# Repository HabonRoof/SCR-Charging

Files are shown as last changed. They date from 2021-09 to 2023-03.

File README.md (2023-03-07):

# Sinusoidal Charger with Optimized Frequency Tracking for Li-ion Batteries

The purpose of this thesis is to develop a sinusoidal charger that can track the optimized frequency of Li-ion batteries.
In this study, the optimized AC impedance frequency tracking is firstly carried out for various types of lithium-ion batteries with different aging degrees to achieve the goal of shortening the charging time and increasing the charging efficiency. 
The digital control core of the charger developed in this thesis uses the F280049C digital signal controller (DSC) produced by Texas Instruments and adopts the Powell algorithm to quickly search for the best sinusoidal charging current frequency when the battery state-of-charge (SOC) is 0%, 15% and 30%, which ensures the lowest impedance during charging.
The proposed prototyping circuit uses field effect transistors as voltage-to-current converters and utilizes digital finite impulse response filters and proportional-integral controllers to stabilize the charging current. 
The charger can provide a maximum charging power of 21W. The experimental results show that the proposed sinusoidal charger can shorten the charging time by 3.66%, reduce the charging loss by 1.08% and reduce the temperature rise by 27.16% compared with the traditional constant current and constant voltage charging method.
Keyword: Sinusoidal Charging, Li-ion Batteries, Fast Charging technique, On-line Optimized Impedance Tracking

[Thesis link](https://ndltd.ncl.edu.tw/cgi-bin/gs32/gsweb.cgi/login?o=dwebmge)

# Outlook
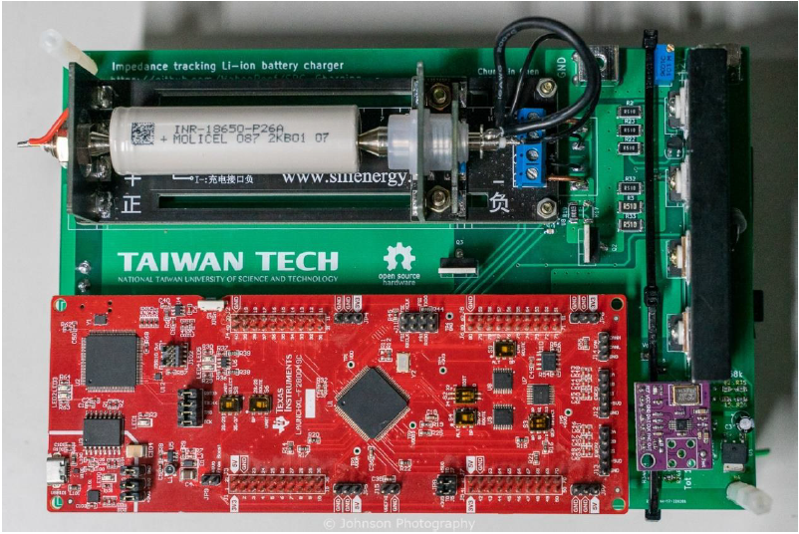
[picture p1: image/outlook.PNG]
Front side


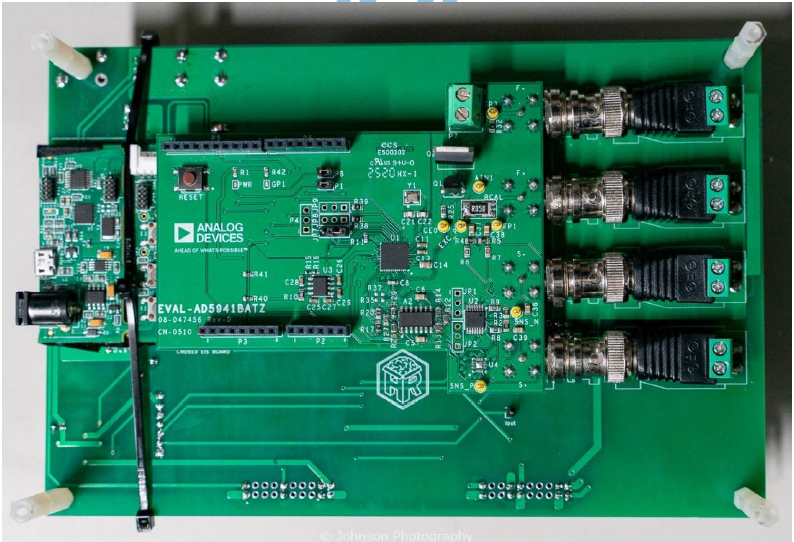
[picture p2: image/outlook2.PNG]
Back side


# File disceiption
#### AD5940_BATImpedance
- ADICuP3029 project, to control and calculate real/imaginary part of impedance. Include FFT calculation.
- Source code for AD5940 battery EIS measurment module (CN0510), modified and origin by Analog Device .Inc.
#### KiCad
- Schematic file and PCB file for main board, which offer CN0510, F280049C Launch Pad and AD9833 waveform generator module a base.
#### RippleCharging
- The main CCS project folder, control the behavior of sinusoidal charger, waveform generator, MOSFET relay, EIS measurement module.
#### ad5940lib
- Companion library of AD5940_BATImpedance folder

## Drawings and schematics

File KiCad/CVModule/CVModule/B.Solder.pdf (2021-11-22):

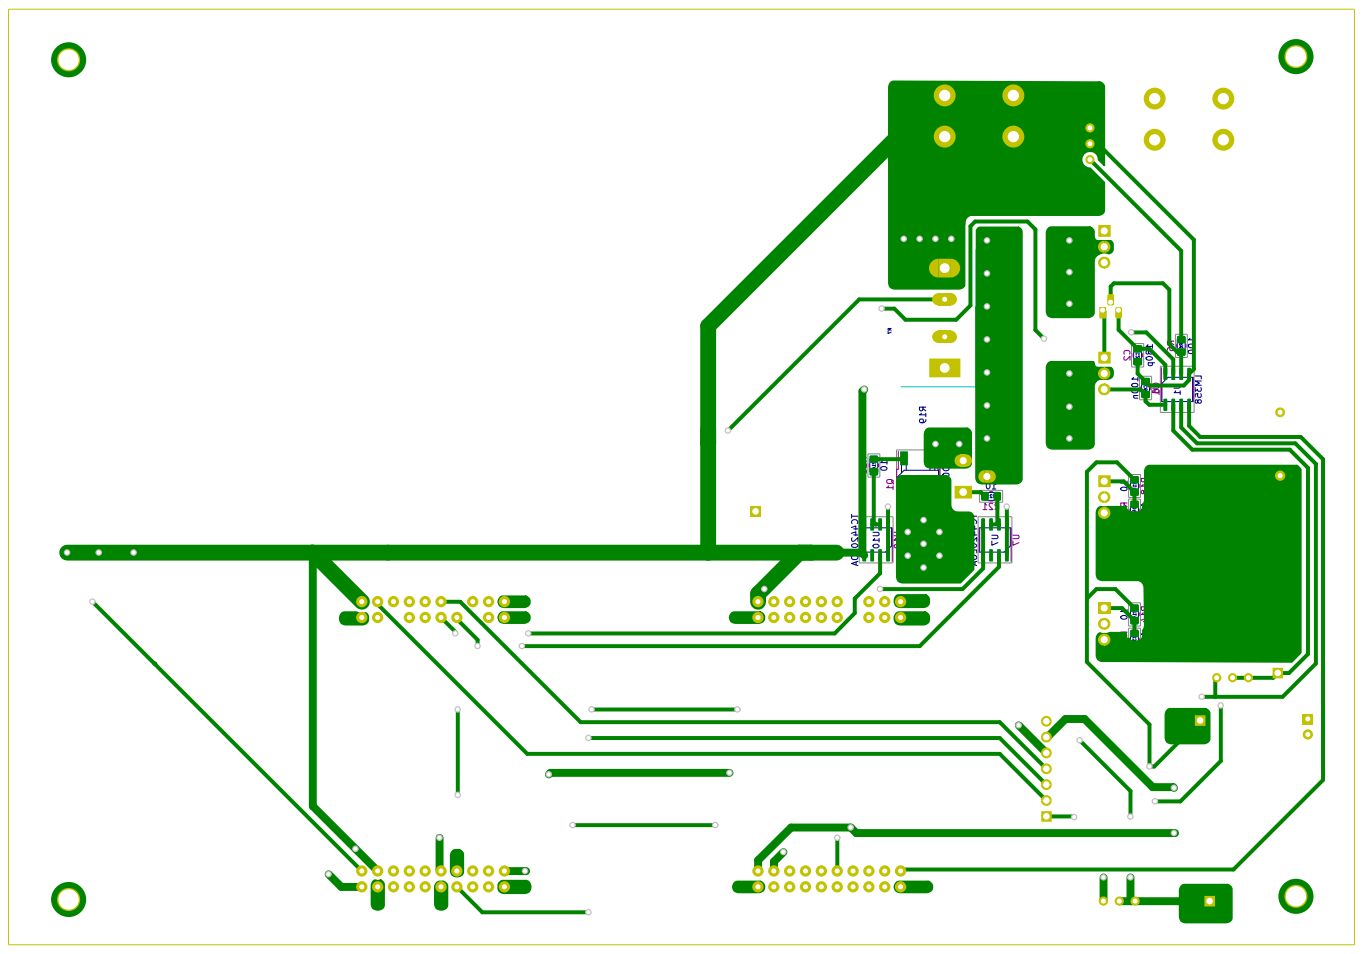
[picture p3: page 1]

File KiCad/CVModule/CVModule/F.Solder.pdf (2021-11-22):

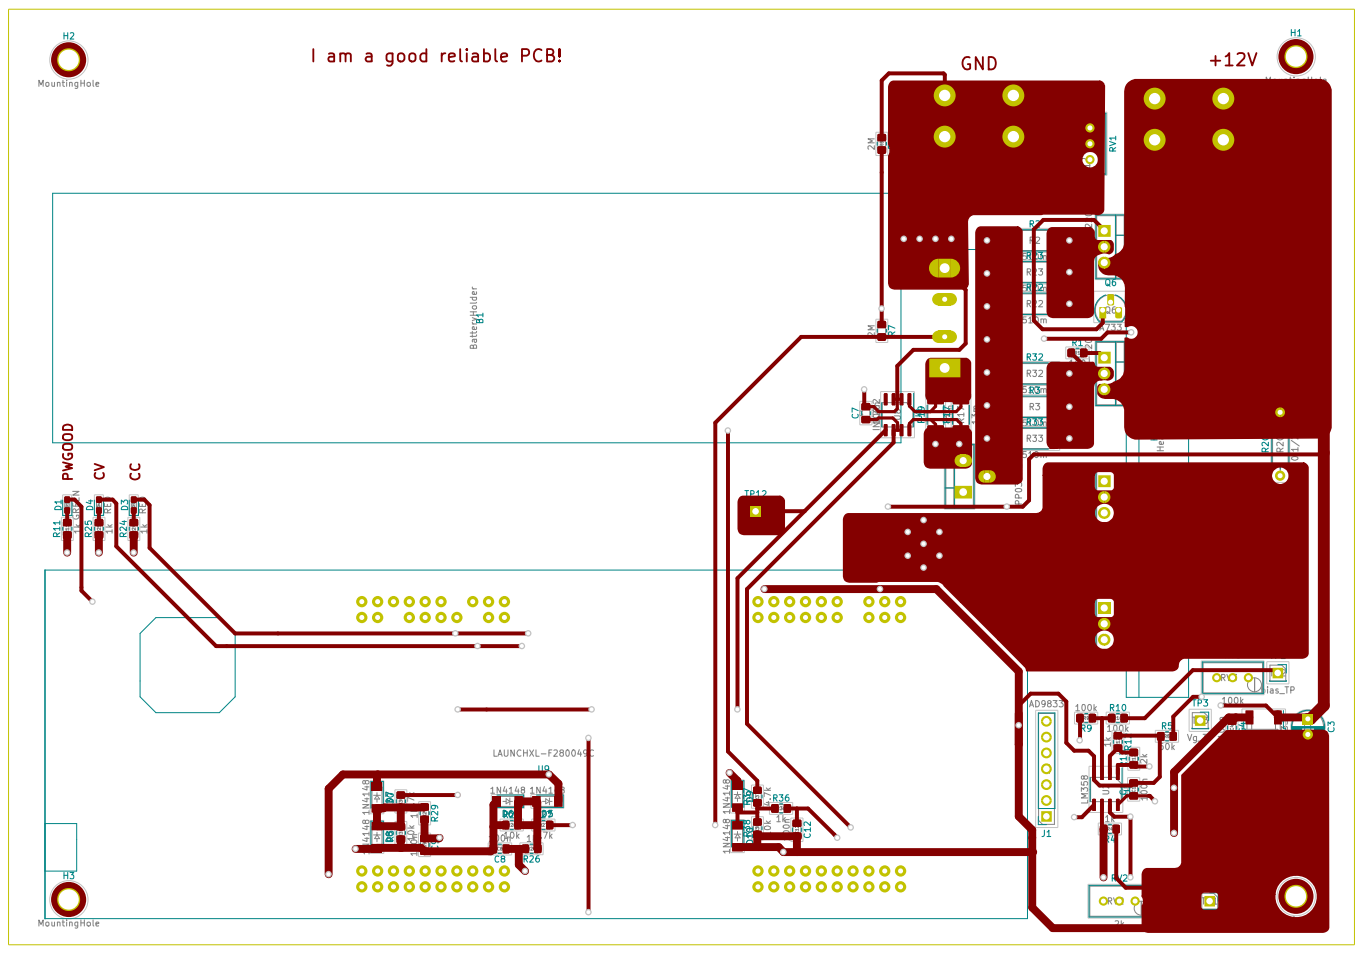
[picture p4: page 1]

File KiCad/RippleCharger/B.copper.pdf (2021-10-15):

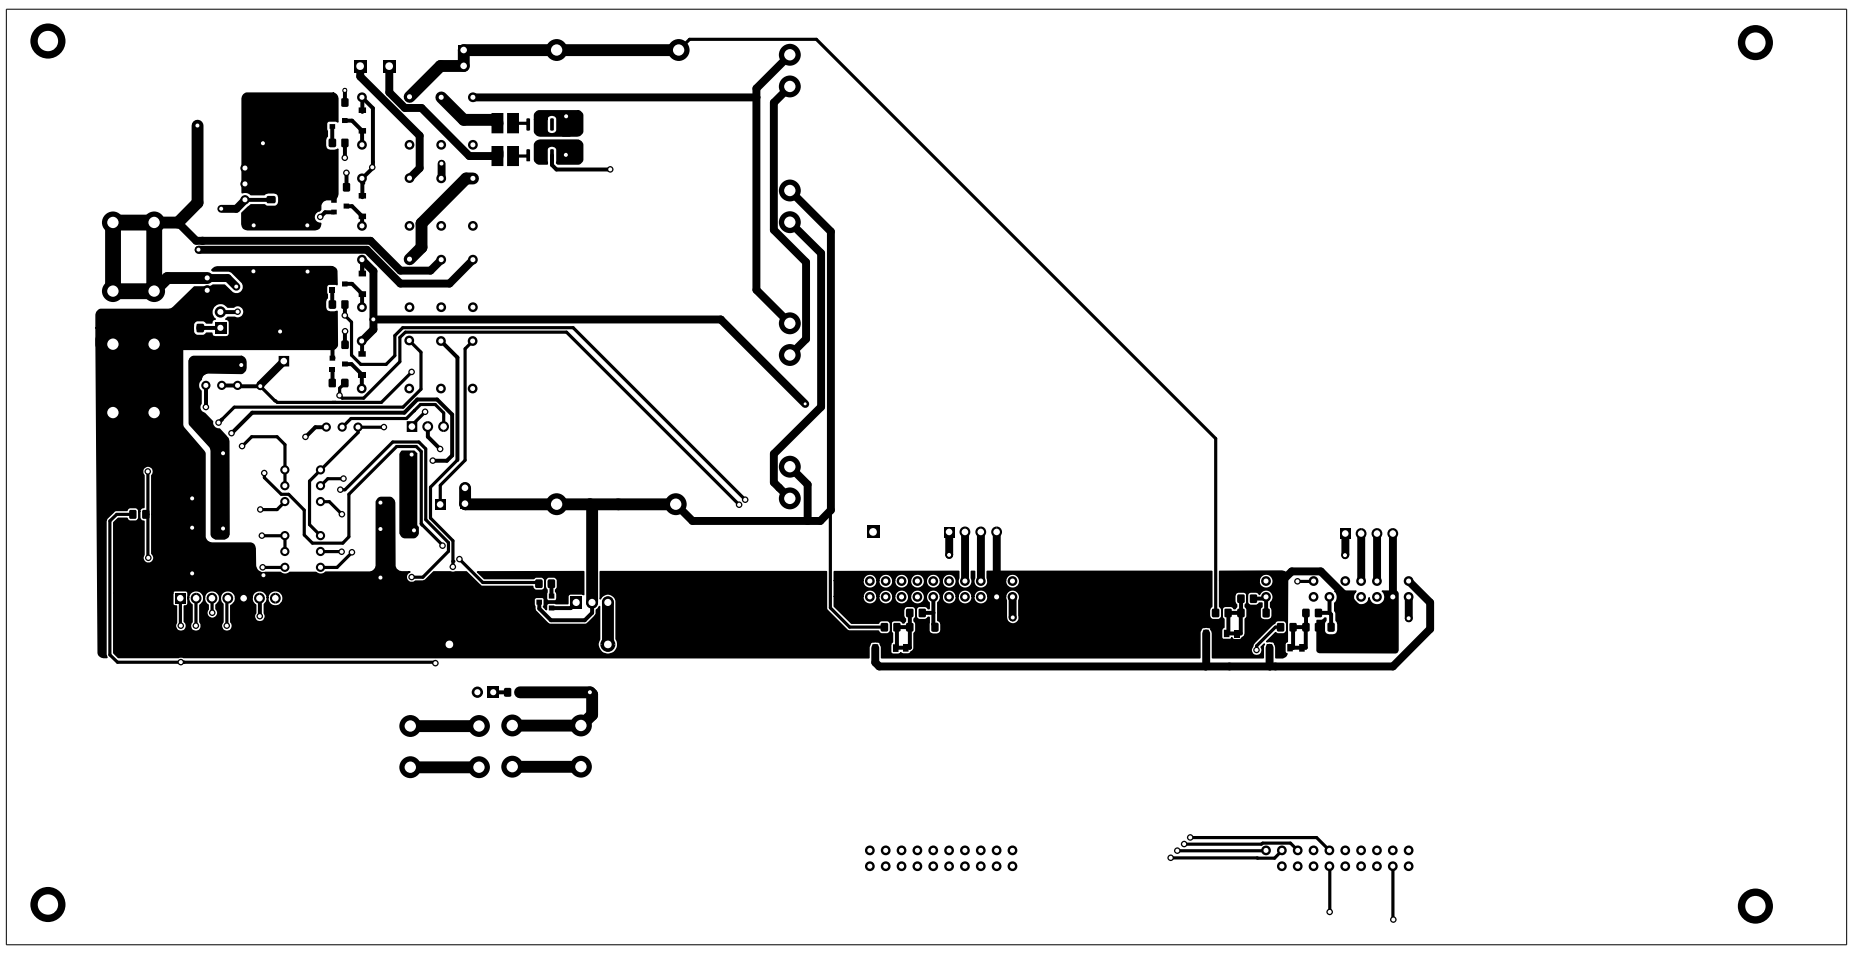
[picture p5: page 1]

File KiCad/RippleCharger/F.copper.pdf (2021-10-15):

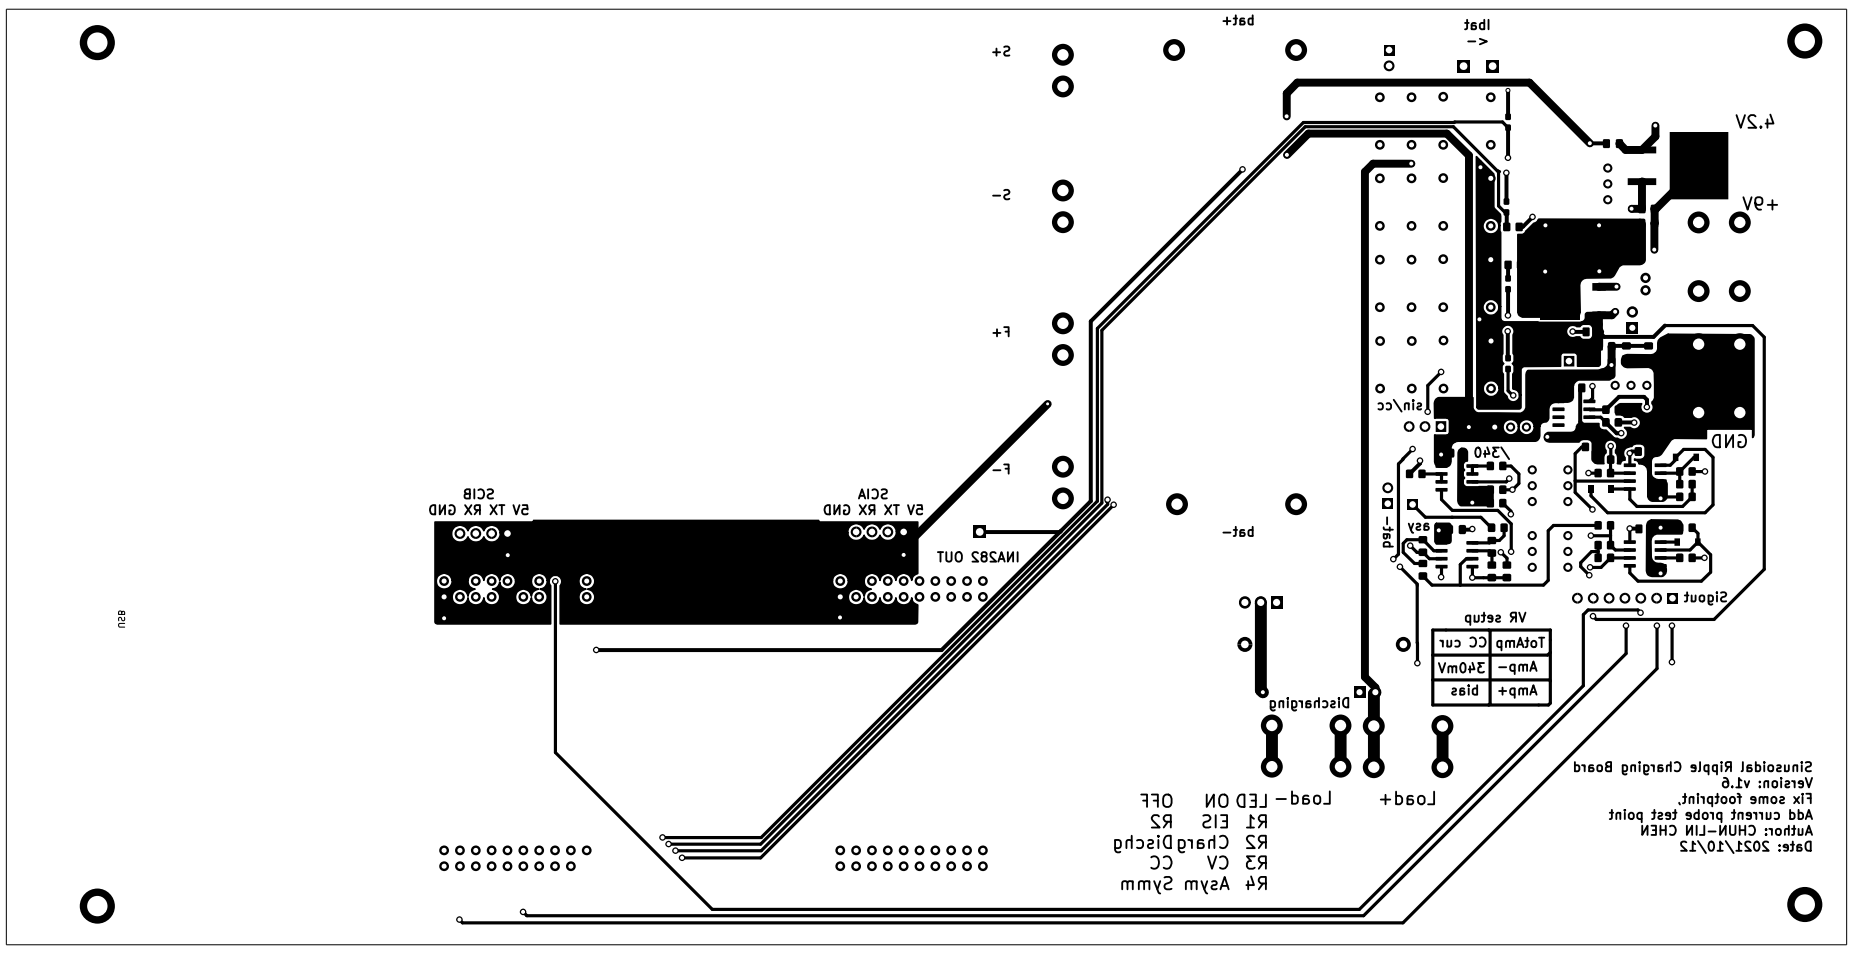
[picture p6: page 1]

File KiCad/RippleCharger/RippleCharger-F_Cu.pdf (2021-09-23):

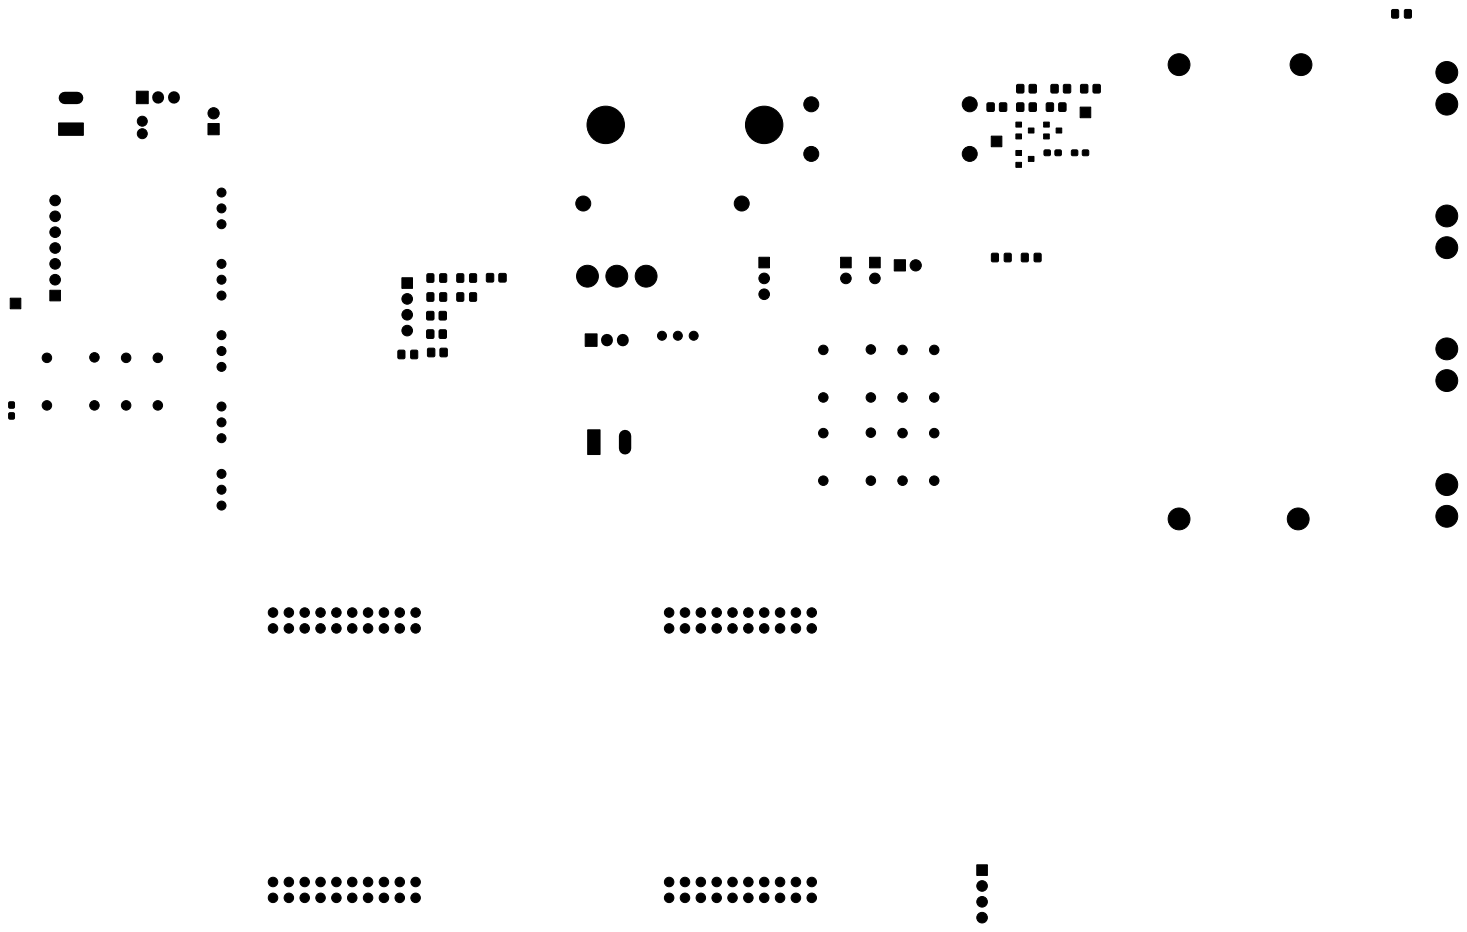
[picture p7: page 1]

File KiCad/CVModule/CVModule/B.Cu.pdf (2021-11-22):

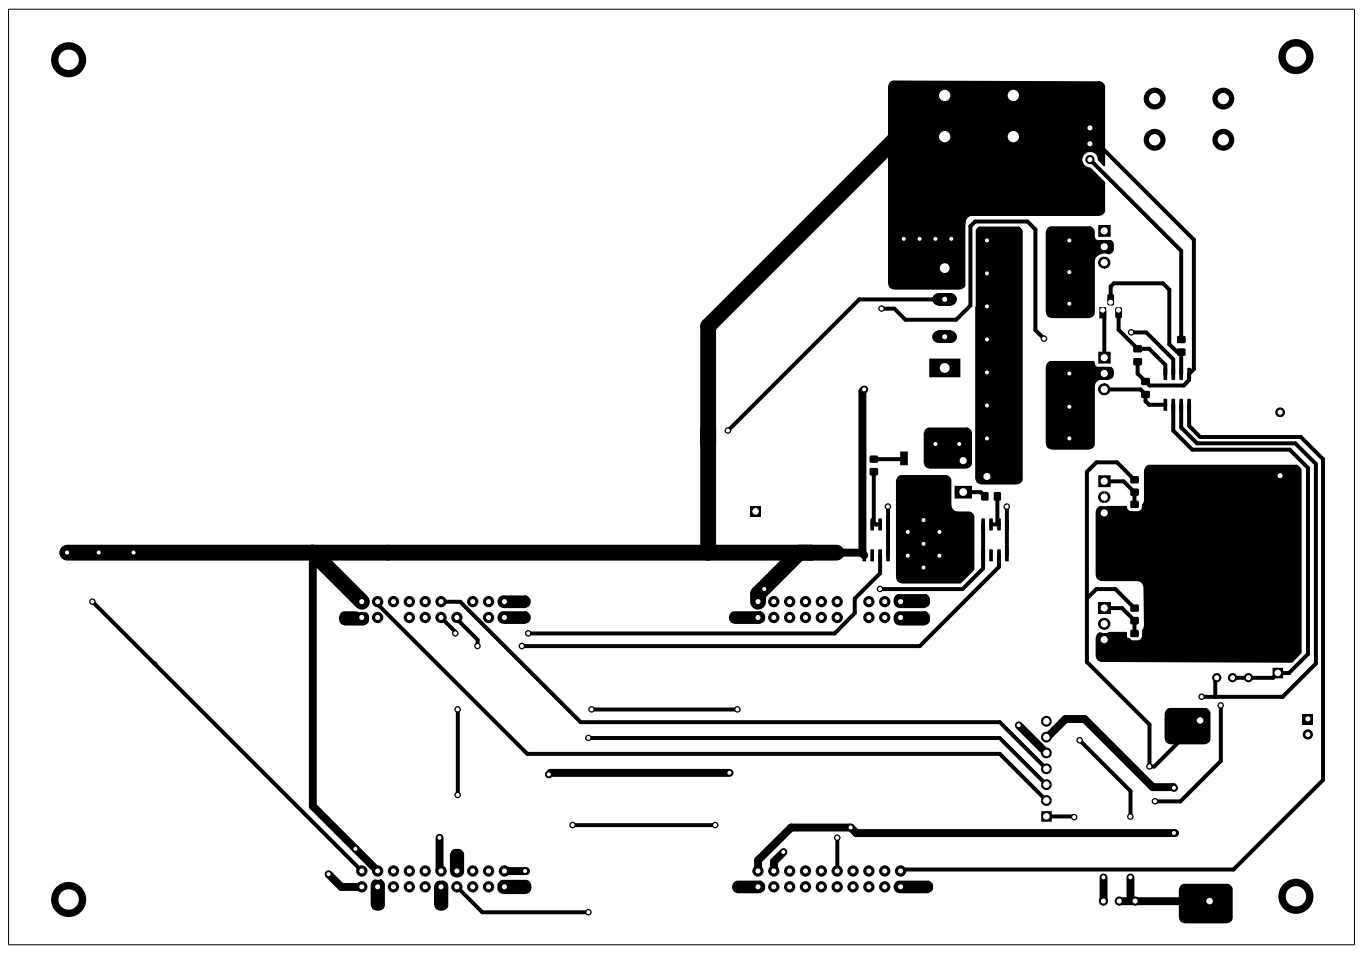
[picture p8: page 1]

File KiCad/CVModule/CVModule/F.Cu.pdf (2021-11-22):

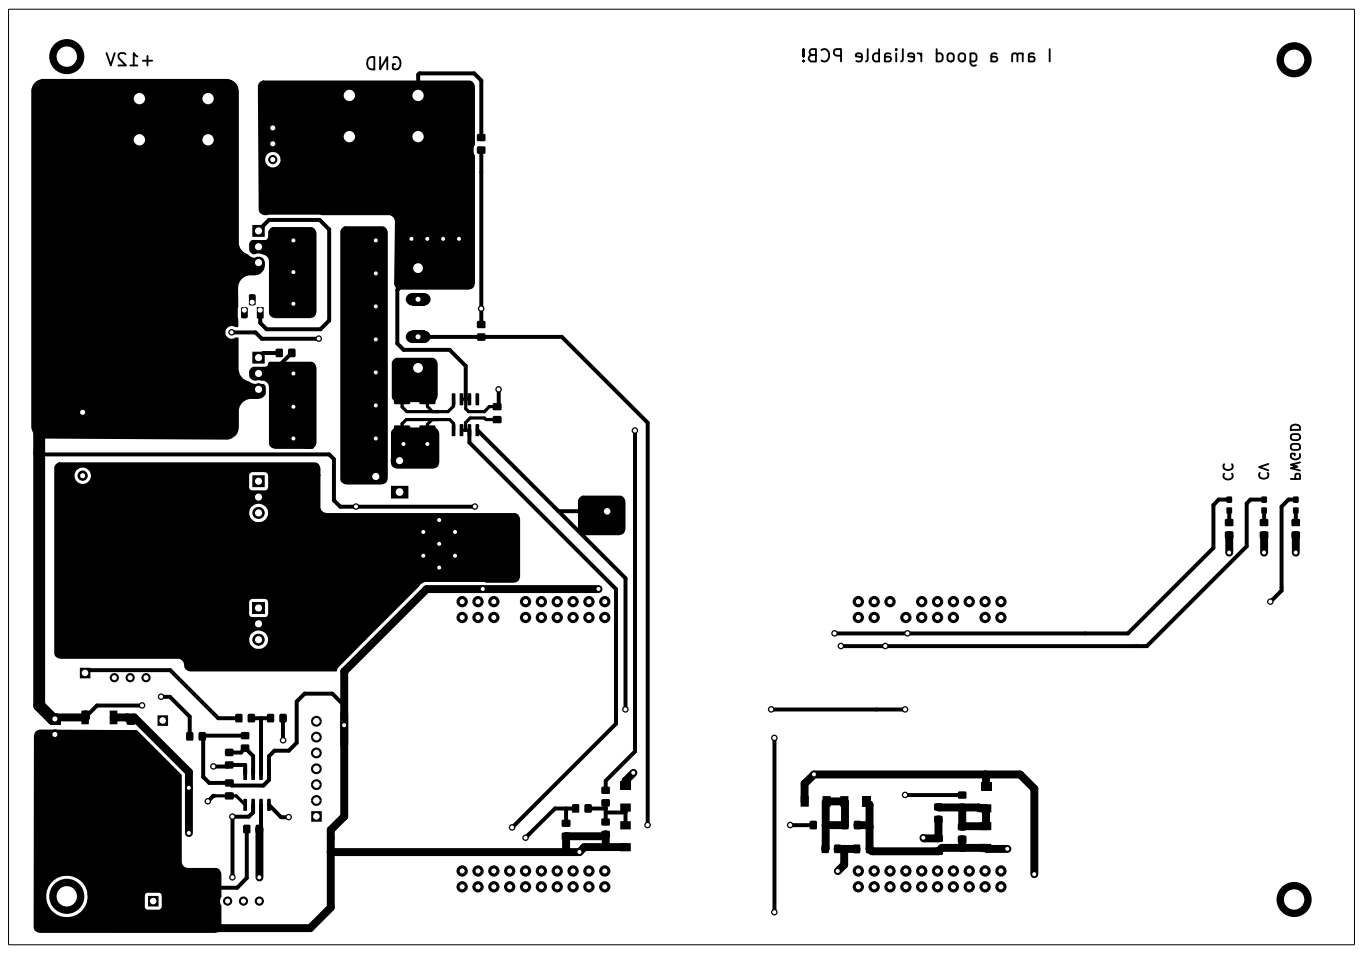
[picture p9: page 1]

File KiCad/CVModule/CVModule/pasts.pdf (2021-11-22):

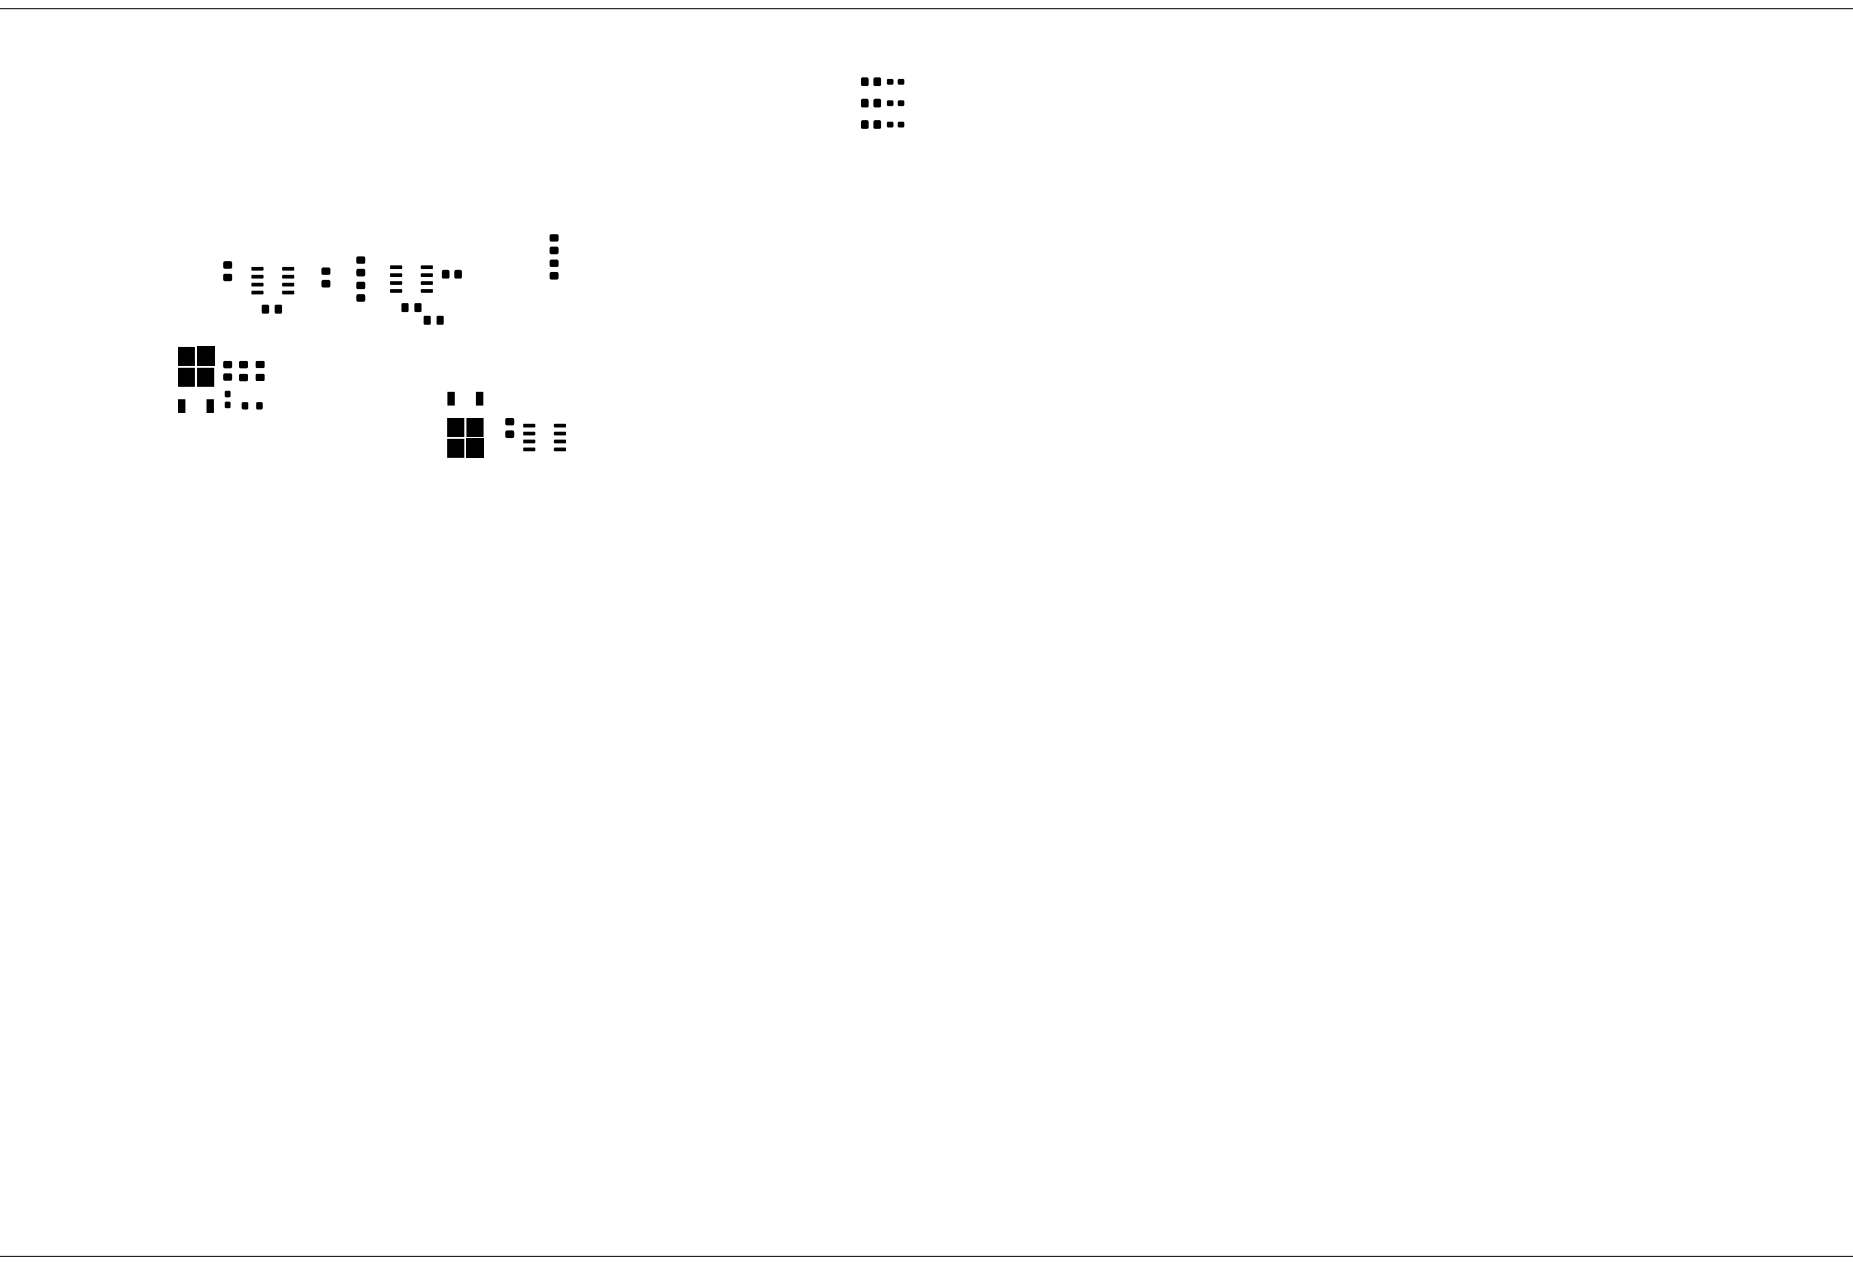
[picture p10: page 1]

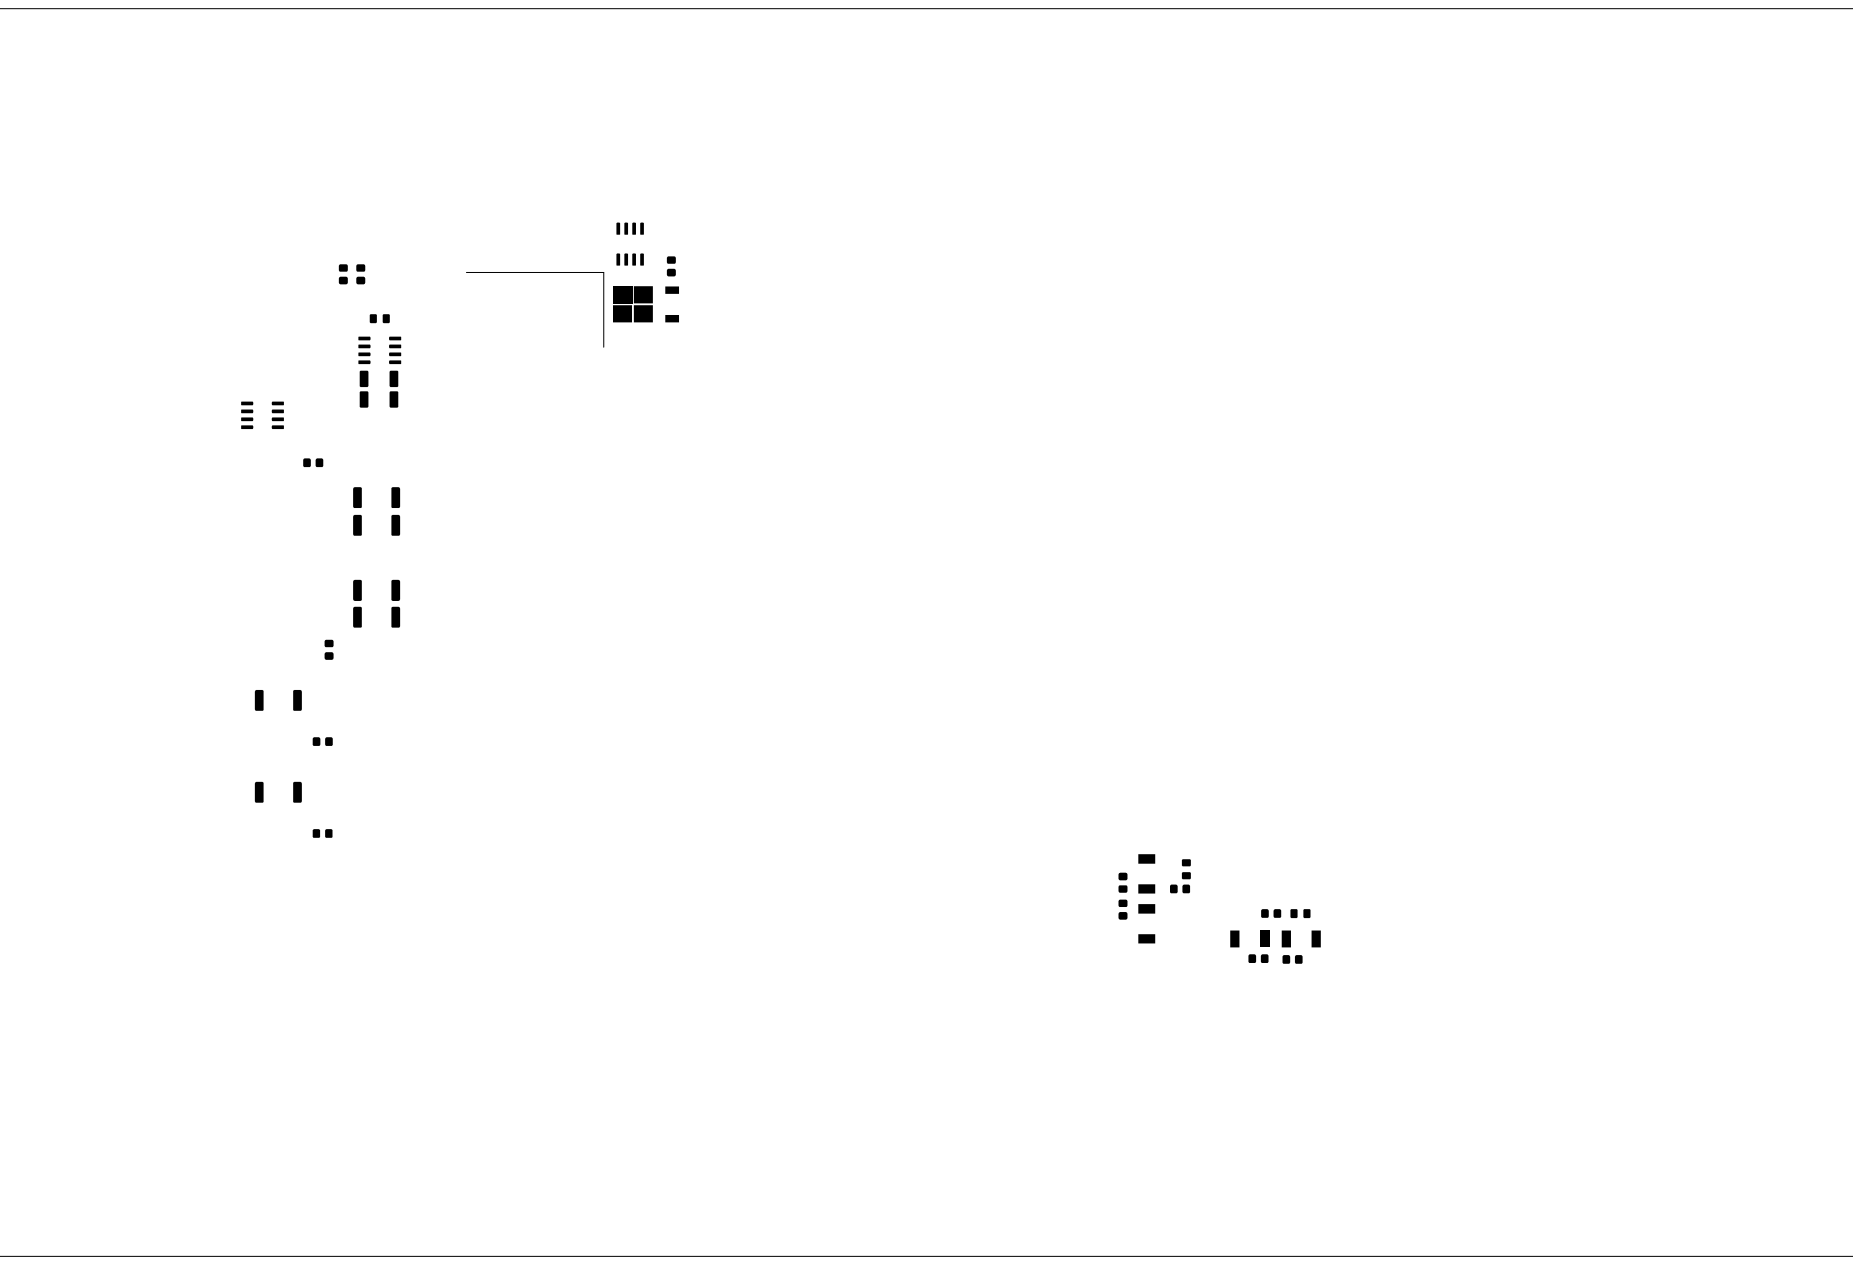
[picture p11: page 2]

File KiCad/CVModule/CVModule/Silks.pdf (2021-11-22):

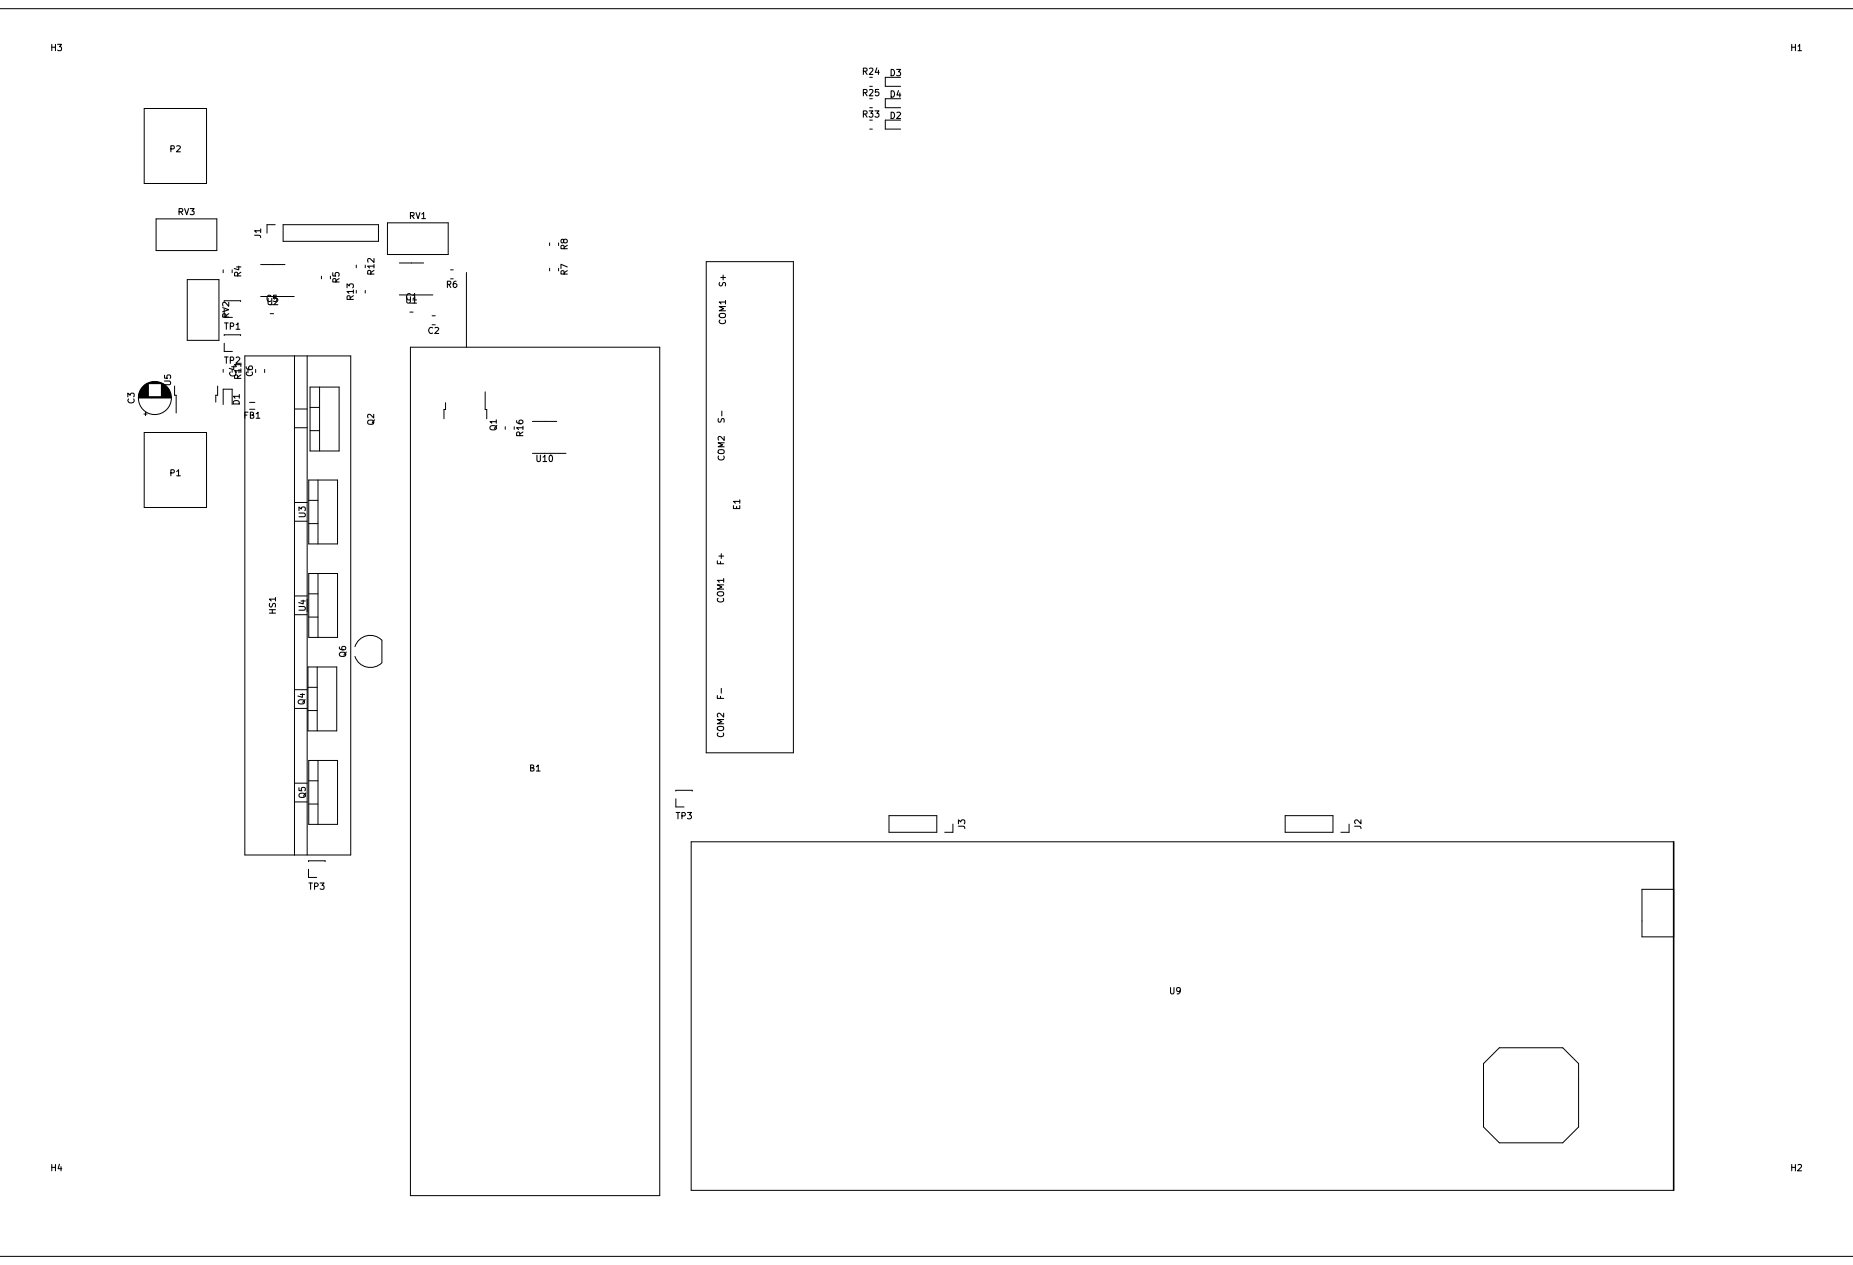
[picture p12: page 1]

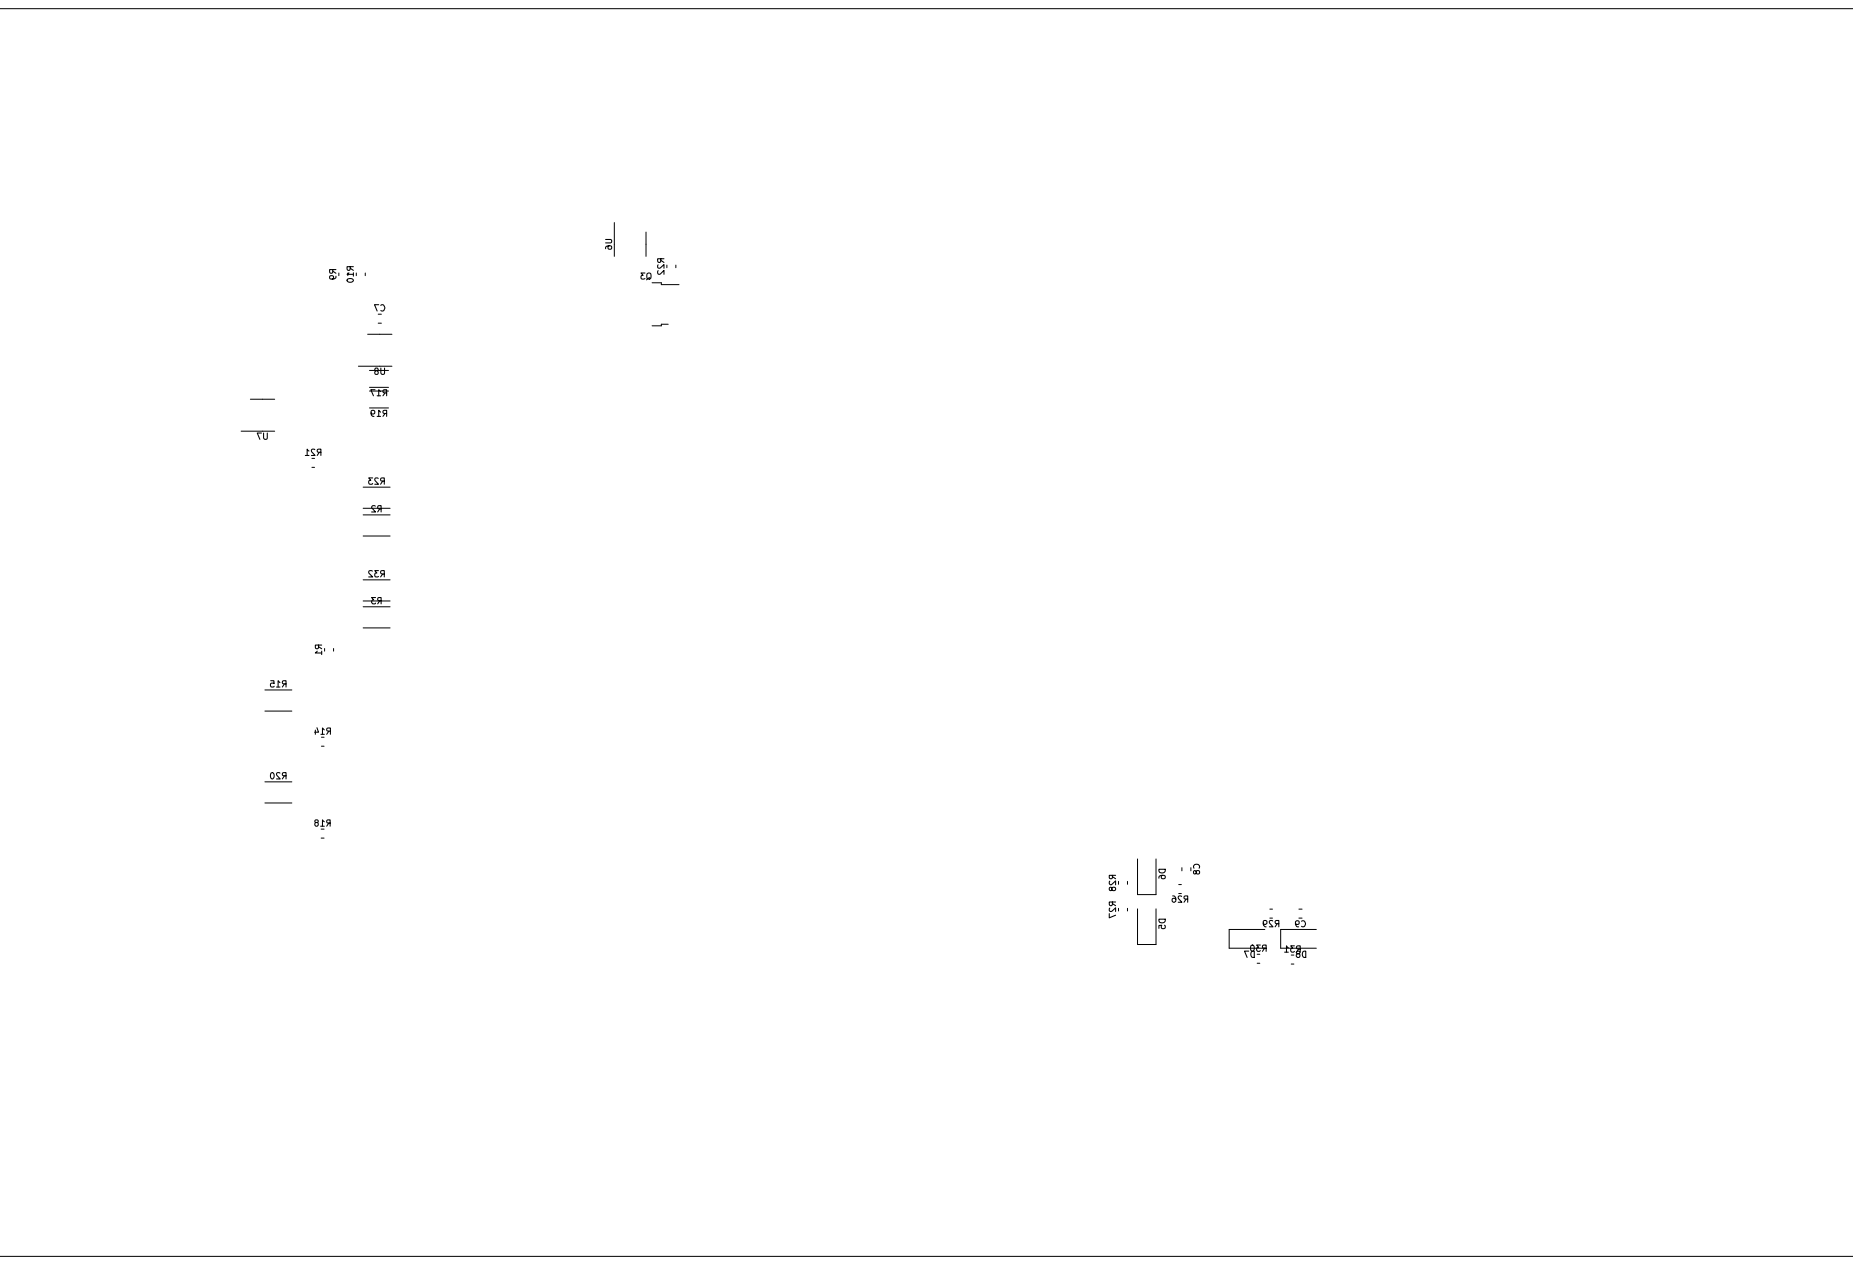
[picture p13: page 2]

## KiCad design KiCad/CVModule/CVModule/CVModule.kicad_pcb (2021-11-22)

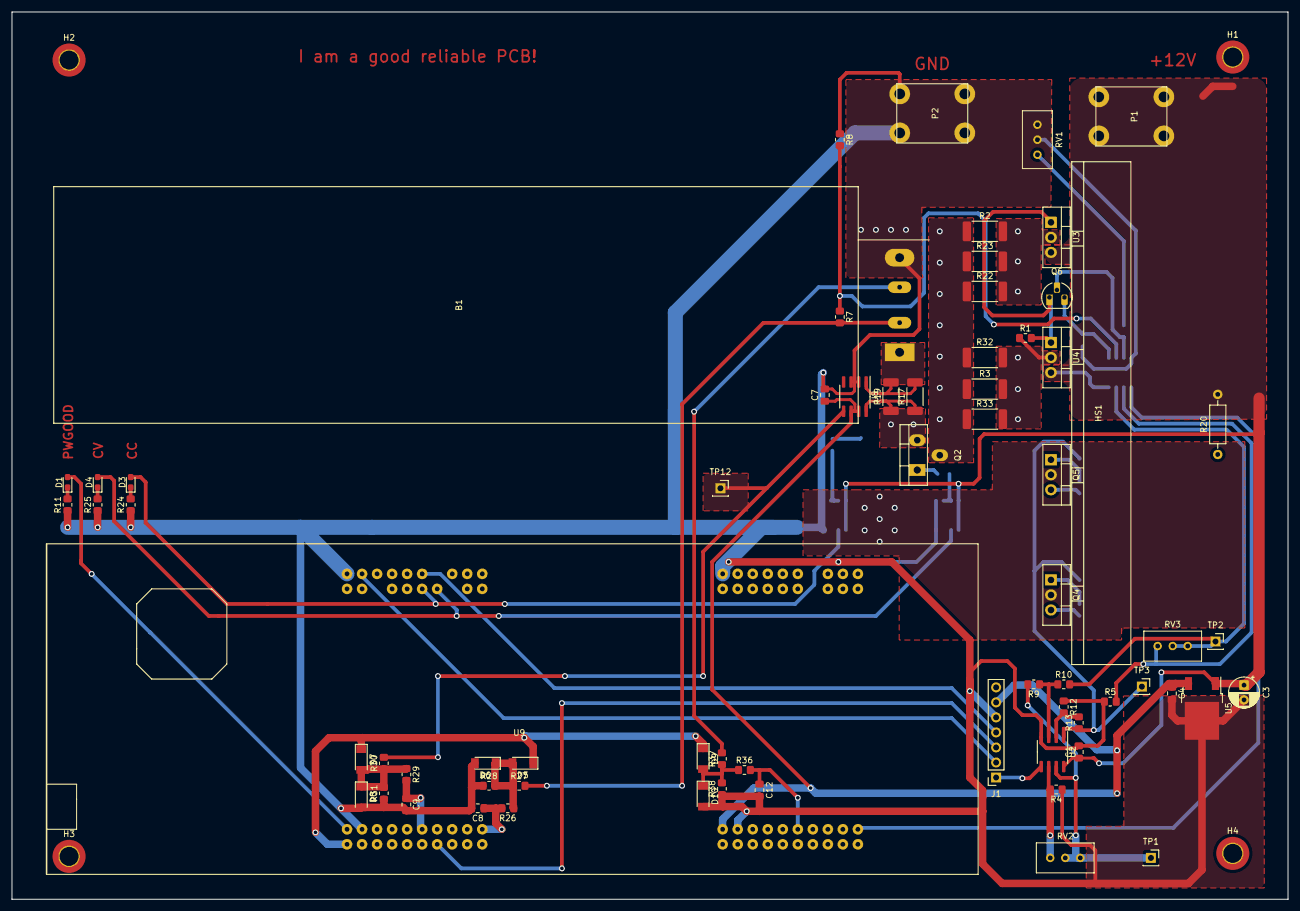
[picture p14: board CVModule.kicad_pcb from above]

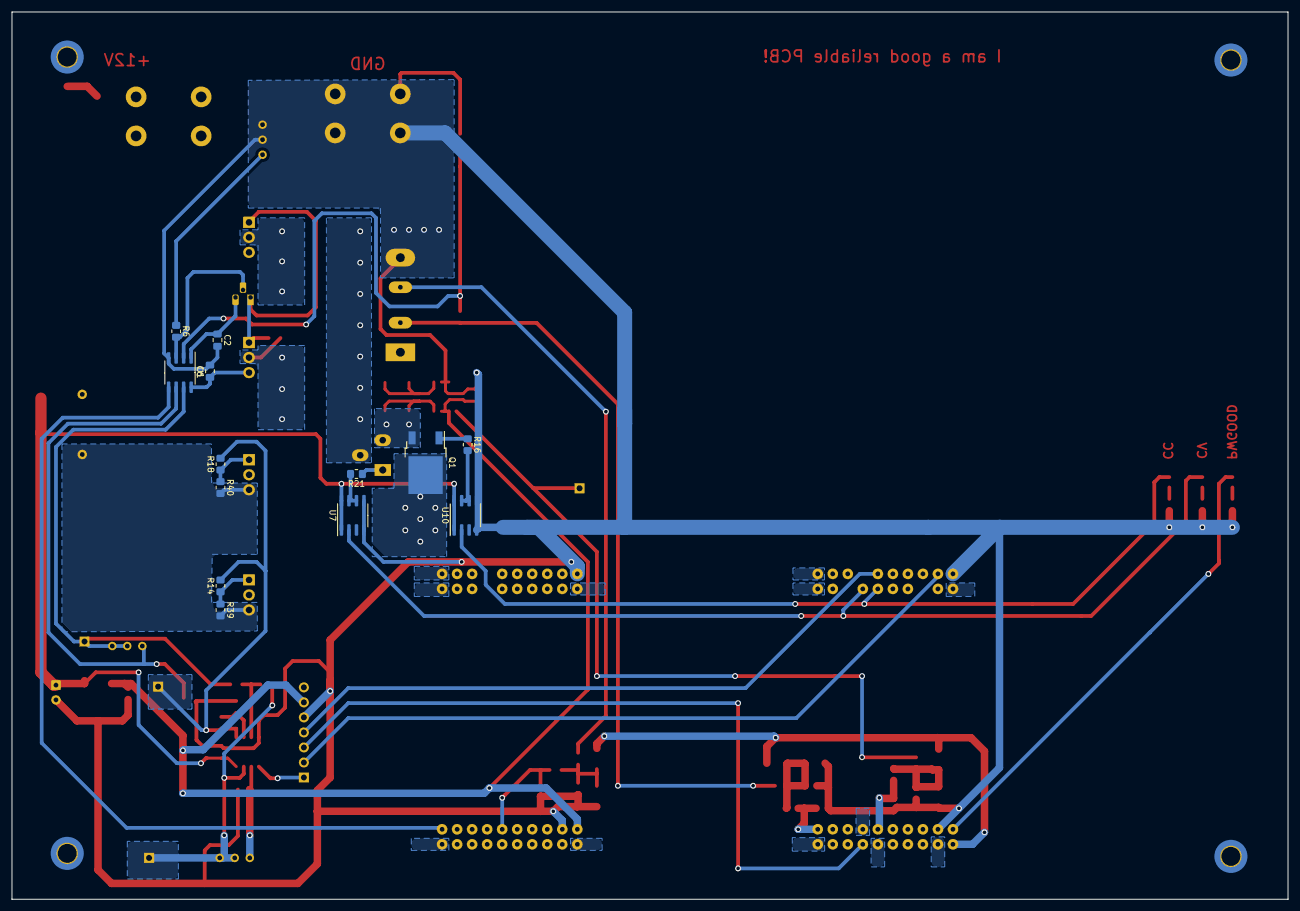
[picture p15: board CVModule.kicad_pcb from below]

Board: 2 copper layers, 215.7 x 150.0 mm, 85 parts (13 on the bottom side), 48 nets.

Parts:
B1: BatteryHolder; BatteryHolder-Single
C1, C4, C6, C7, C8, C9, C12: 100n; C_0805_2012Metric_Pad1.18x1.45mm_HandSolder
C2: 180p; C_0805_2012Metric_Pad1.18x1.45mm_HandSolder
C3: 0.33u; CP_Radial_D5.0mm_P2.50mm
D1: GREEN; LED_0603_1608Metric_Pad1.05x0.95mm_HandSolder
D3, D4: RED; LED_0603_1608Metric_Pad1.05x0.95mm_HandSolder
D5, D6, D7, D8, D9, D10: 1N4148; D_MiniMELF
H1, H2, H3, H4: MountingHole; MountingHole_3.2mm_M3_DIN965_Pad_TopBottom
HS1: Heatsink; Heatsink_80mmx3mm_4hole_black
J1: AD9833; PinSocket_1x07_P2.54mm_Vertical
P1: +12Vin; IOPad
P2: GND; IOPad
Q1: 600N25NG; TO-252-2
Q2: IPP030N10N3; TO220-3_Vertical_T
Q4, Q5: IRFR9024; TO-220-3_Vertical
Q6: A733; TO-92_HandSolder
R1, R6: 100; R_0805_2012Metric_Pad1.20x1.40mm_HandSolder
R2, R3, R22, R23, R32, R33: 510m; R_2512_6332Metric_Pad1.40x3.35mm_HandSolder
R4, R11, R12, R24, R25, R26, R29, R36: 1k; R_0805_2012Metric_Pad1.20x1.40mm_HandSolder
R5: 50k; R_0805_2012Metric_Pad1.20x1.40mm_HandSolder
R7, R8: 2M; R_0805_2012Metric_Pad1.20x1.40mm_HandSolder
R9, R10: 100k; R_0805_2012Metric_Pad1.20x1.40mm_HandSolder
R13: 2k; R_0805_2012Metric_Pad1.20x1.40mm_HandSolder
R14, R16, R18, R21: 10; R_0805_2012Metric_Pad1.20x1.40mm_HandSolder
R17, R19: 13m; R_2010_5025Metric_Pad1.40x2.65mm_HandSolder
R20: 0.1/2W; R_Axial_DIN0207_L6.3mm_D2.5mm_P10.16mm_Horizontal
R27, R30, R37: 4.7k; R_0805_2012Metric_Pad1.20x1.40mm_HandSolder
R28, R31, R38, R39, R40: 10k; R_0805_2012Metric_Pad1.20x1.40mm_HandSolder
RV1: 1k; Potentiometer_Bourns_3296W_Vertical
RV2: 2k; Potentiometer_Bourns_3296W_Vertical
RV3: 100k; Potentiometer_Bourns_3296W_Vertical
TP1: sig_TP; PinSocket_1x01_P2.54mm_Vertical
TP2: bias_TP; PinSocket_1x01_P2.54mm_Vertical
TP3: Vg_TP; PinSocket_1x01_P2.54mm_Vertical
TP12: Iout; PinSocket_1x01_P2.54mm_Vertical
U1, U2: LM358; SOIC-8_3.9x4.9mm_P1.27mm
U3, U4: LM317_TO-220; TO-220-3_Vertical
U5: L7805; TO-252-2
U7, U10: TC4420EOA; SOIC-8_3.9x4.9mm_P1.27mm
U8: INA282; SOIC-8_3.9x4.9mm_P1.27mm
U9: LAUNCHXL-F280049C; LANCHXL-F280049C

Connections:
+3V3: D5.1, D7.1, D9.1, U9.1
+4.2V: Q2.2, R2.1, R3.1, R22.1, R23.1, R32.1, R33.1
+5V: C4.1, C7.1, D1.2, J1.6, U5.3, U8.6, U8.7, U9.21, U9.61
+12V: C1.1, C3.1, C6.1, P1.1, R20.2, U1.8, U2.8, U3.3, U4.3, U5.1, U7.1, U7.8, U10.1, U10.8
-BATT: B1.4, C1.2, C2.2, C3.2, C4.2, C6.2, C7.2, C8.2, C9.2, C12.2, D6.2, D8.2, D10.2, J1.5, P2.1, R4.1, R5.1, R8.1, R11.1, R12.1, R24.1, R25.1, R28.1, R31.1, R38.1, RV1.2, RV1.3, U1.4, U2.4, U5.2, U7.4, U7.5, U8.2, U8.3, U9.20, U9.22, U9.60, U9.62, U10.4, U10.5
CC_g: D3.2, U9.35, U10.2
CS: J1.2, U9.19
CV_g: D4.2, U7.2, U9.34
Iout: R30.2, TP12.1, U8.5
MOSI: J1.4, U9.15
unnamed: C2.1, Q6.3, U1.1
unnamed: D1.1, R11.2
unnamed: D3.1, R24.2
unnamed: D4.1, R25.2
unnamed: D5.2, D6.1, R26.1, R27.1, R28.2
unnamed: D7.2, D8.1, R29.1, R30.1, R31.2
unnamed: D9.2, D10.1, R36.1, R37.1, R38.2
unnamed: Q1.1, R16.1
unnamed: Q1.2, Q4.2, Q5.2
unnamed: Q2.1, R21.1
unnamed: Q4.1, R14.1, R39.1
unnamed: Q4.3, Q5.3, R20.1, R39.2, R40.2
unnamed: Q5.1, R18.1, R40.1
unnamed: Q6.1, R1.2, U3.1, U4.1
unnamed: Q6.2, R6.2, U1.3
unnamed: R1.1, R3.2, R32.2, R33.2, U4.2
unnamed: R2.2, R22.2, R23.2, U3.2
unnamed: R4.2, RV2.3, U2.6
unnamed: R5.2, RV3.3, U1.6
unnamed: R6.1, RV1.1
unnamed: R7.1, R8.2, U1.2
unnamed: R9.2, RV2.1, RV2.2, TP1.1, U2.7
unnamed: R9.1, R10.1, U2.3
unnamed: R10.2, RV3.1, RV3.2, TP2.1, U1.7
unnamed: R12.2, R13.2, U2.2
Q1_g: R16.2, U10.6, U10.7
Q2_g: R21.2, U7.6, U7.7
Rs+: Q1.3, Q2.3, R17.1, R19.1, U8.8
Rs-: B1.1, R17.2, R19.2, U8.1
SCLK: J1.3, U9.7
Vbat+: C8.1, R26.2, U9.30
Vbat-: C12.1, R36.2, U9.66
Viout: C9.1, R29.2, U9.26
bat+: B1.2, R7.2, R27.2
bat-: B1.3, R37.2
bias_ctl: U1.5, U9.70
signal: R13.1, R14.2, R18.2, TP3.1, U2.1
sigout: J1.1, U2.5

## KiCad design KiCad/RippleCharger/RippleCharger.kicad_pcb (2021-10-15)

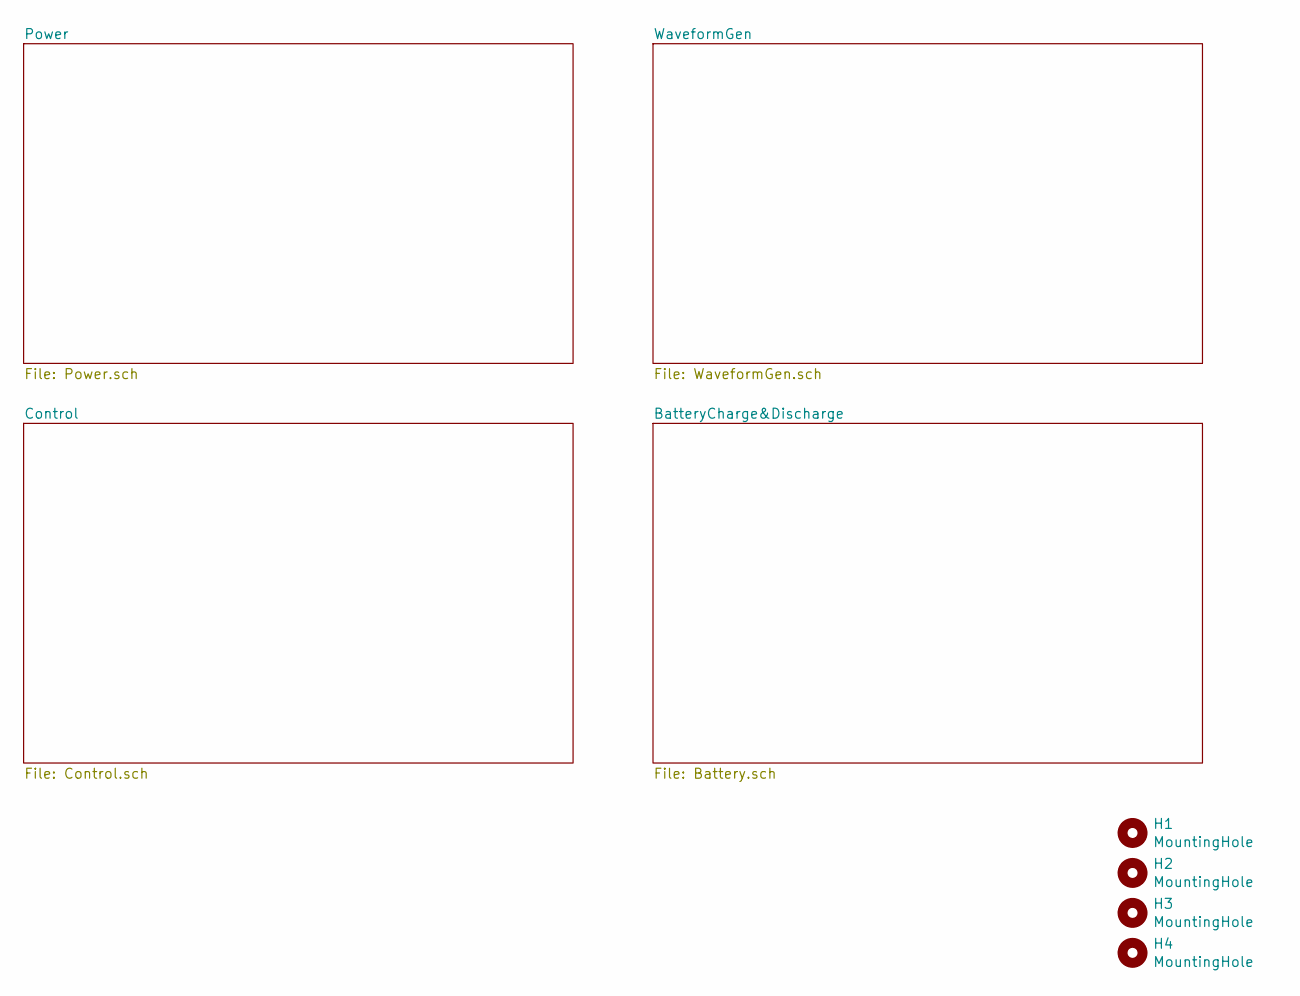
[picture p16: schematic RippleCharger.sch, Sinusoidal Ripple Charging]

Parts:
H1, H2, H3, H4: MountingHole; MountingHole_3.2mm_M3_DIN965_Pad_TopBottom

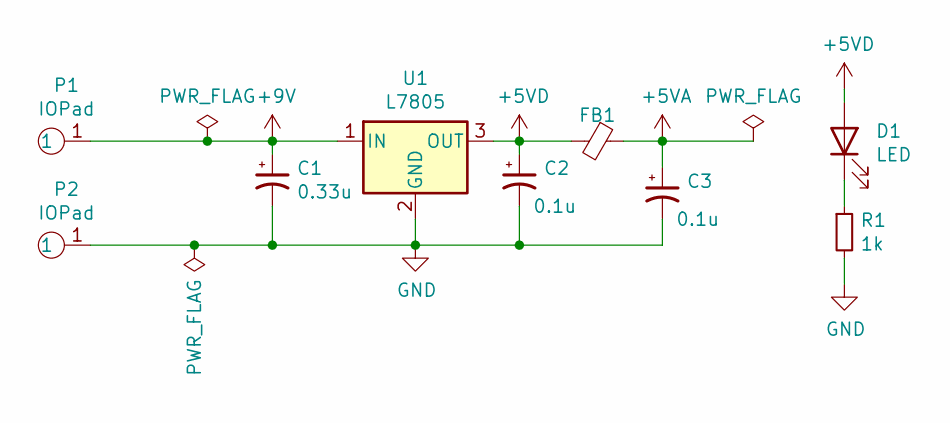
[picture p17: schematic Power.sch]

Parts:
C1: 0.33u; C_Radial_D5.0mm_H11.0mm_P2.00mm
C2, C3: 0.1u; C_0805_2012Metric_Pad1.18x1.45mm_HandSolder
D1: LED; LED_D3.0mm
FB1: Ferrite_Bead_Small; R_0805_2012Metric_Pad1.20x1.40mm_HandSolder
P1, P2: IOPad
R1: 1k; R_0805_2012Metric_Pad1.20x1.40mm_HandSolder
U1: L7805; TO-252-2

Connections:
+5VA: C3.1, FB1.1; also elsewhere on the board
+5VD: C2.1, D1.2 (A), FB1.2, U1.3 (OUT); also elsewhere on the board
+9V: C1.1, P1.1, U1.1 (IN); also elsewhere on the board
GND: C1.2, C2.2, C3.2, P2.1, R1.2, U1.2 (GND); also elsewhere on the board
unnamed: D1.1 (K), R1.1

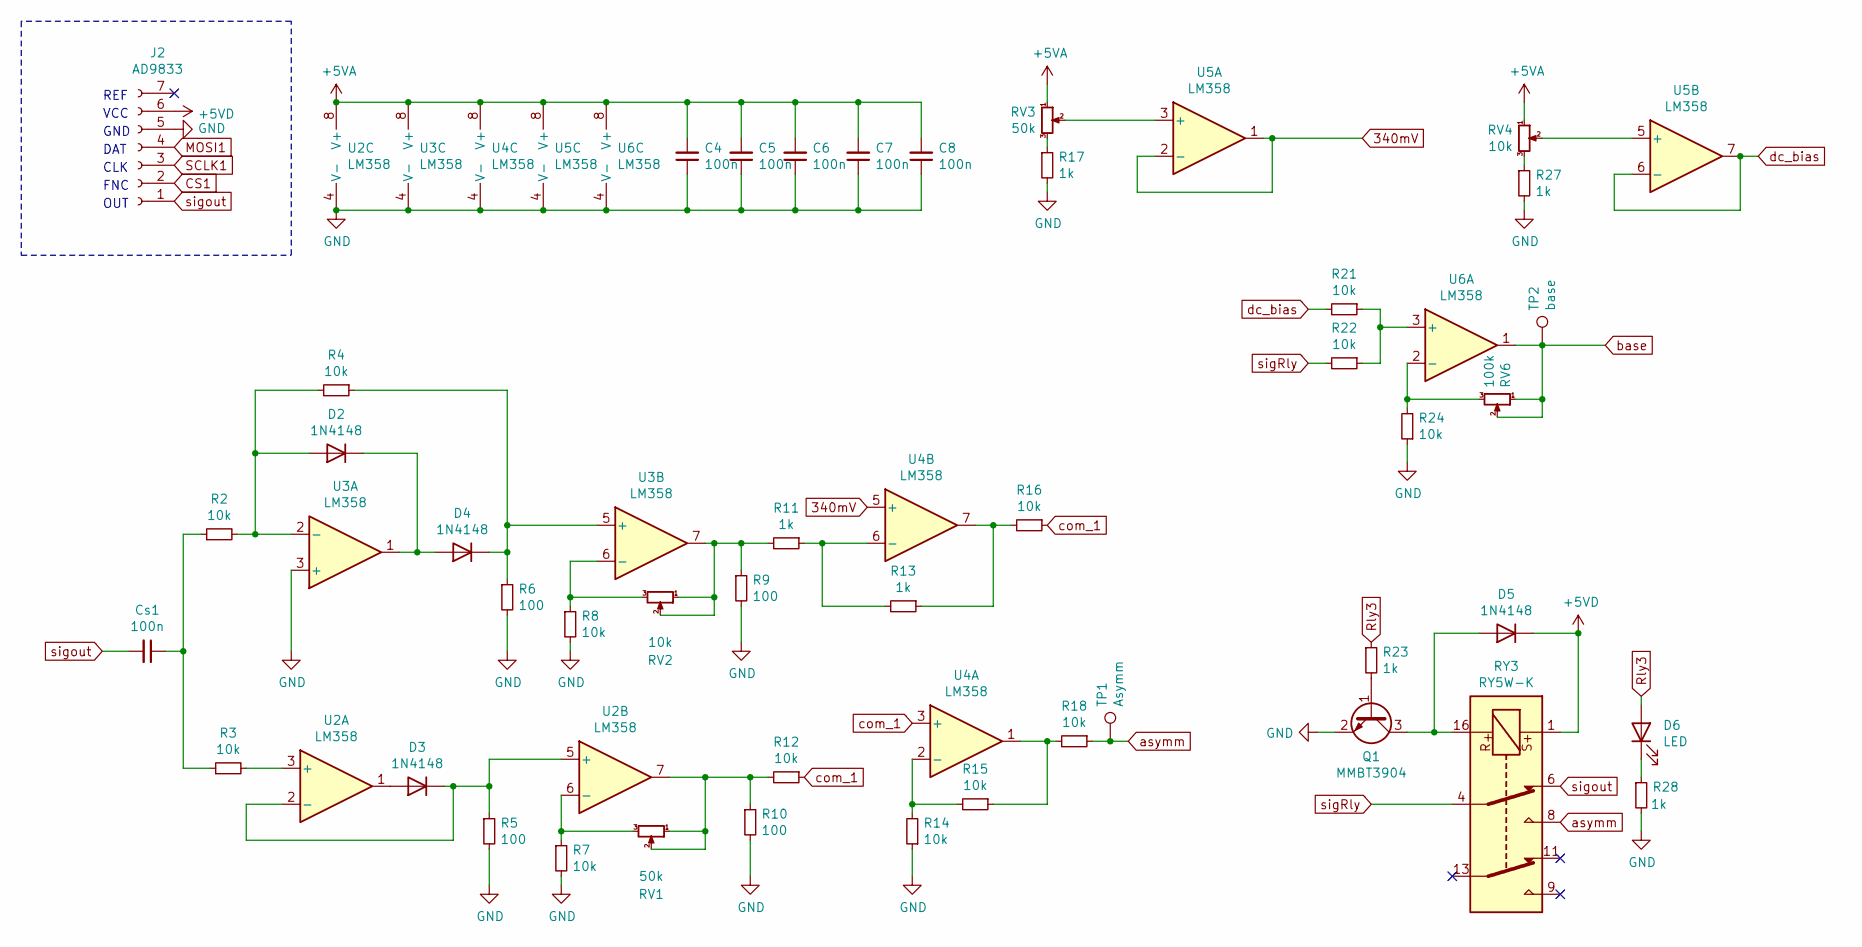
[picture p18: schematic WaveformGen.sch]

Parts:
C4, C5, C6, C7, C8: 100n; C_0805_2012Metric_Pad1.18x1.45mm_HandSolder
Cs1: 100n; C_0805_2012Metric_Pad1.18x1.45mm_HandSolder
D2, D3, D4, D5: 1N4148; D_SOD-123
D6: LED; LED_0603_1608Metric_Pad1.05x0.95mm_HandSolder
J2: AD9833; PinHeader_1x07_P2.54mm_Vertical
Q1: MMBT3904; SOT-23
R2, R3, R4, R7, R8, R12, R14, R15, R16, R18, R21, R22, R24: 10k; R_0805_2012Metric_Pad1.20x1.40mm_HandSolder
R5, R6, R9, R10: 100; R_0805_2012Metric_Pad1.20x1.40mm_HandSolder
R11, R13, R17, R23, R27, R28: 1k; R_0805_2012Metric_Pad1.20x1.40mm_HandSolder
RV1, RV3: 50k; Potentiometer_Bourns_3296W_Vertical
RV2, RV4: 10k; Potentiometer_Bourns_3296W_Vertical
RV6: 100k; Potentiometer_Bourns_3296W_Vertical
RY3: RY5W-K
TP1: Asymm; PinHeader_1x01_P2.54mm_Vertical
TP2: base; PinHeader_1x01_P2.54mm_Vertical
U2, U3, U4, U5, U6: LM358; SOIC-8_3.9x4.9mm_P1.27mm

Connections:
340mV: U4.5 (+), U5.1, U5.2 (-)
+5VA: C4.2, C5.2, C6.2, C7.2, C8.2, RV3.1, RV4.1, U2.8 (V+), U3.8 (V+), U4.8 (V+), U5.8 (V+), U6.8 (V+); also elsewhere on the board
+5VD: D5.1 (K), J2.6, RY3.1; also elsewhere on the board
CS1: J2.2; also elsewhere on the board
GND: C4.1, C5.1, C6.1, C7.1, C8.1, J2.5, Q1.2 (E), R5.2, R6.2, R7.2, R8.2, R9.2, R10.2, R14.1, R17.2, R24.1, R27.2, R28.2, U2.4 (V-), U3.3 (+), U3.4 (V-), U4.4 (V-), U5.4 (V-), U6.4 (V-); also elsewhere on the board
MOSI1: J2.4; also elsewhere on the board
unnamed: Cs1.1, R2.1, R3.1
unnamed: D2.1 (K), D4.2 (A), U3.1
unnamed: D2.2 (A), R2.2, R4.2, U3.2 (-)
unnamed: D3.1 (K), R5.1, U2.2 (-), U2.5 (+)
unnamed: D3.2 (A), U2.1
unnamed: D4.1 (K), R4.1, R6.1, U3.5 (+)
unnamed: D5.2 (A), Q1.3 (C), RY3.16
unnamed: D6.1 (K), R28.1
unnamed: Q1.1 (B), R23.2
unnamed: R3.2, U2.3 (+)
unnamed: R7.1, RV1.3, U2.6 (-)
unnamed: R8.1, RV2.3, U3.6 (-)
unnamed: R10.1, R12.2, RV1.1, RV1.2, U2.7
unnamed: R11.1, R13.2, U4.6 (-)
unnamed: R9.1, R11.2, RV2.1, RV2.2, U3.7
unnamed: R13.1, R16.2, U4.7
unnamed: R14.2, R15.2, U4.2 (-)
unnamed: R15.1, R18.2, U4.1
unnamed: R17.1, RV3.3
unnamed: R21.1, R22.1, U6.3 (+)
unnamed: R24.2, RV6.3, U6.2 (-)
unnamed: R27.1, RV4.3
unnamed: RV3.2, U5.3 (+)
unnamed: RV4.2, U5.5 (+)
Rly3: D6.2 (A), R23.1; also elsewhere on the board
SCLK1: J2.3; also elsewhere on the board
asymm: R18.1, RY3.8, TP1.1
base: RV6.1, RV6.2, TP2.1, U6.1; also elsewhere on the board
com_1: R12.1, R16.1, U4.3 (+)
dc_bias: R21.2, U5.6 (-), U5.7
sigRly: R22.2, RY3.4
sigout: Cs1.2, J2.1, RY3.6

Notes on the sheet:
REF
VCC
GND
DAT
CLK
FNC
OUT

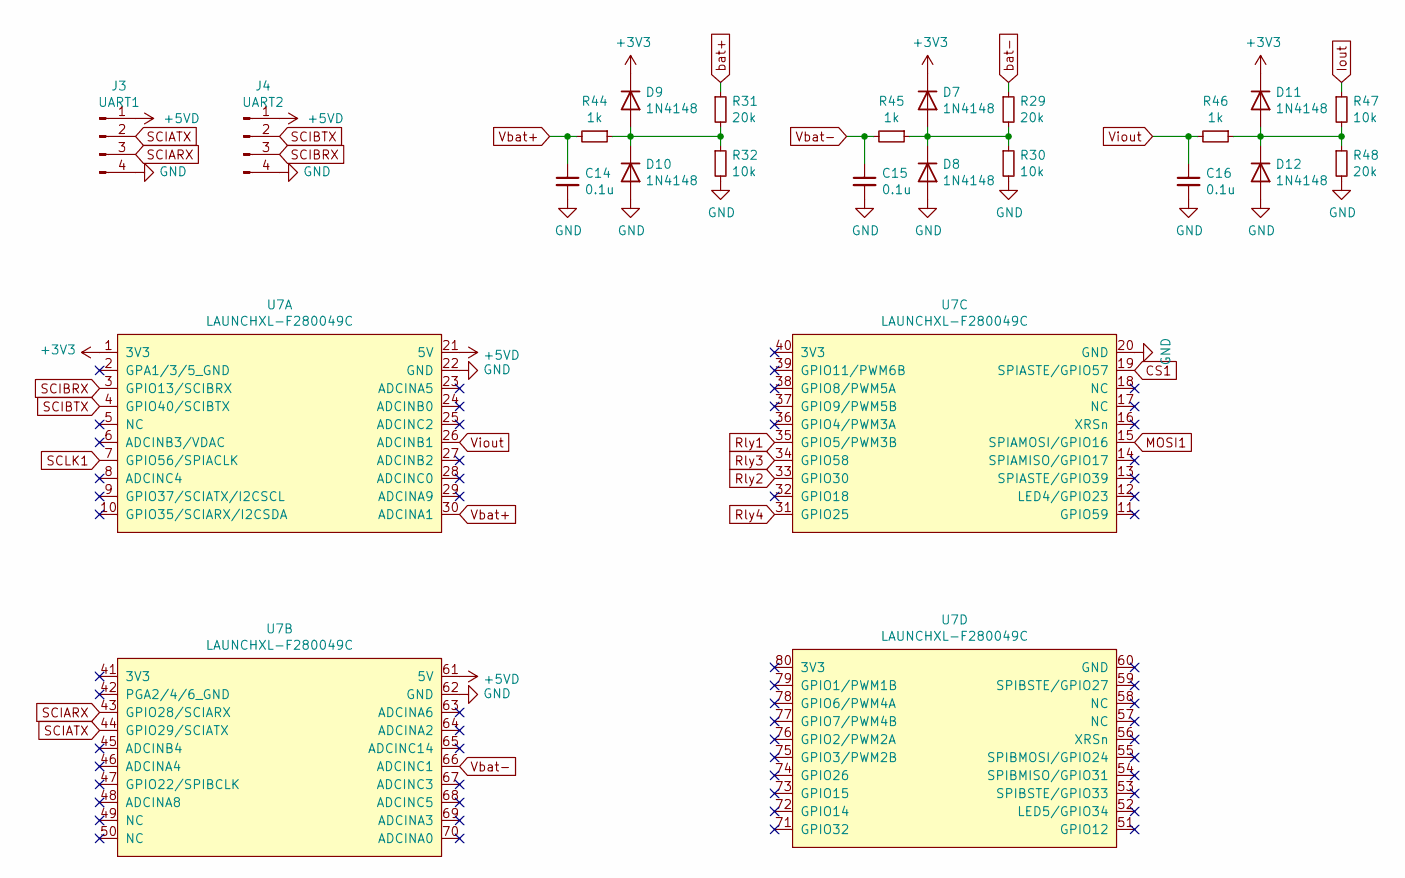
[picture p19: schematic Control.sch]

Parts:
C14, C15, C16: 0.1u; C_0805_2012Metric_Pad1.18x1.45mm_HandSolder
D7, D8, D9, D10, D11, D12: 1N4148; D_SOD-123
J3: UART1; PinHeader_1x04_P2.54mm_Vertical
J4: UART2; PinHeader_1x04_P2.54mm_Vertical
R29, R31, R48: 20k; R_0805_2012Metric_Pad1.20x1.40mm_HandSolder
R30, R32, R47: 10k; R_0805_2012Metric_Pad1.20x1.40mm_HandSolder
R44, R45, R46: 1k; R_0805_2012Metric_Pad1.20x1.40mm_HandSolder
U7: LAUNCHXL-F280049C; LANCHXL-F280049C

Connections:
+3V3: D7.1 (K), D9.1 (K), D11.1 (K), U7.1 (3V3)
+5VD: J3.1, J4.1, U7.21 (5V), U7.61 (5V); also elsewhere on the board
CS1: U7.19 (SPIASTE/GPIO57); also elsewhere on the board
GND: C14.2, C15.2, C16.2, D8.2 (A), D10.2 (A), D12.2 (A), J3.4, J4.4, R30.2, R32.2, R48.2, U7.20 (GND), U7.22 (GND), U7.62 (GND); also elsewhere on the board
MOSI1: U7.15 (SPIAMOSI/GPIO16); also elsewhere on the board
unnamed: D7.2 (A), D8.1 (K), R29.2, R30.1, R45.1
unnamed: D9.2 (A), D10.1 (K), R31.2, R32.1, R44.1
unnamed: D11.2 (A), D12.1 (K), R46.1, R47.2, R48.1
Rly1: U7.35 (GPIO5/PWM3B); also elsewhere on the board
Rly2: U7.33 (GPIO30); also elsewhere on the board
Rly3: U7.34 (GPIO58); also elsewhere on the board
Rly4: U7.31 (GPIO25); also elsewhere on the board
SCIARX: J3.3, U7.43 (GPIO28/SCIARX)
SCIATX: J3.2, U7.44 (GPIO29/SCIATX)
SCIBRX: J4.3, U7.3 (GPIO13/SCIBRX)
SCIBTX: J4.2, U7.4 (GPIO40/SCIBTX)
SCLK1: U7.7 (GPIO56/SPIACLK); also elsewhere on the board
Vbat+: C14.1, R44.2, U7.30 (ADCINA1)
Vbat-: C15.1, R45.2, U7.66 (ADCINC1)
Viout: C16.1, R46.2, U7.26 (ADCINB1)
bat+: R31.1; also elsewhere on the board
bat-: R29.1; also elsewhere on the board

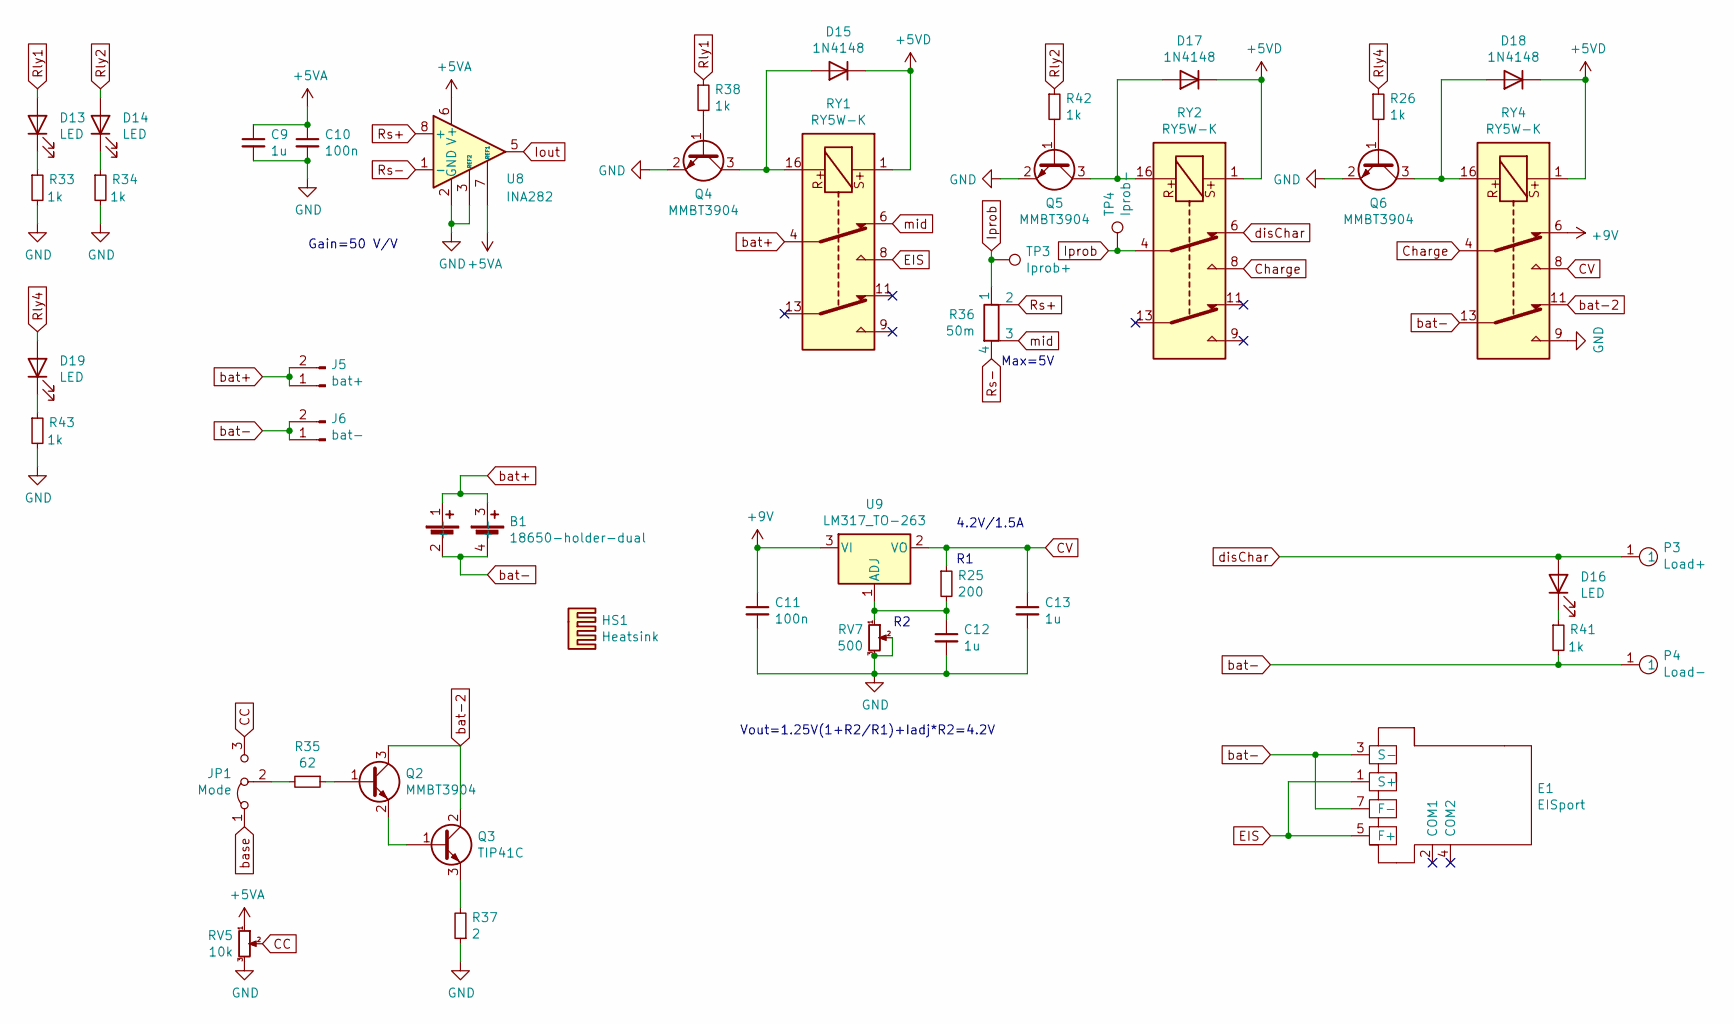
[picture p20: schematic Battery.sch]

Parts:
B1: 18650-holder-dual
C9, C12, C13: 1u; C_0805_2012Metric_Pad1.18x1.45mm_HandSolder
C10, C11: 100n; C_0805_2012Metric_Pad1.18x1.45mm_HandSolder
D13, D14, D19: LED; LED_0603_1608Metric_Pad1.05x0.95mm_HandSolder
D15, D17, D18: 1N4148; D_SOD-123
D16: LED; LED_D3.0mm
E1: EISport; CN0510_BNC
HS1: Heatsink; Heatsink_Fischer_SK104-STCB_35x13mm__2xDrill3.5mm_ScrewM3
J5: bat+; PinHeader_1x02_P2.54mm_Vertical
J6: bat-; PinHeader_1x02_P2.54mm_Vertical
JP1: Mode; PinHeader_1x03_P2.54mm_Vertical
P3: Load+; IOPad
P4: Load-; IOPad
Q2, Q4, Q5, Q6: MMBT3904; SOT-23
Q3: TIP41C; TO-220-3_Vertical
R25: 200; R_0805_2012Metric_Pad1.20x1.40mm_HandSolder
R26, R33, R34, R38, R41, R42, R43: 1k; R_0805_2012Metric_Pad1.20x1.40mm_HandSolder
R35: 62; R_0805_2012Metric_Pad1.20x1.40mm_HandSolder
R36: 50m; R_Shunt_Ohmite_LVK24
R37: 2; R_Axial_Power_L20.0mm_W6.4mm_P25.40mm
RV5: 10k; Potentiometer_Bourns_3296W_Vertical
RV7: 500; Potentiometer_Bourns_3296W_Vertical
RY1, RY2, RY4: RY5W-K
TP3: Iprob+; PinHeader_1x01_P2.54mm_Vertical
TP4: Iprob-; PinHeader_1x01_P2.54mm_Vertical
U8: INA282; SOIC-8_3.9x4.9mm_P1.27mm
U9: LM317_TO-263; TO-263-2

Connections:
+5VA: C9.1, C10.1, RV5.1, U8.6 (V+), U8.7 (REF1); also elsewhere on the board
+5VD: D15.1 (K), D17.1 (K), D18.1 (K), RY1.1, RY2.1, RY4.1; also elsewhere on the board
+9V: C11.1, RY4.6, U9.3 (VI); also elsewhere on the board
CC: JP1.3 (B), RV5.2
CV: C13.1, R25.1, RY4.8, U9.2 (VO)
Charge: RY2.8, RY4.4
EIS: E1.1 (S+), E1.5 (F+), RY1.8
GND: C9.2, C10.2, C11.2, C12.2, C13.2, Q4.2 (E), Q5.2 (E), Q6.2 (E), R33.2, R34.2, R37.1, R43.2, RV5.3, RV7.2, RV7.3, RY4.9, U8.2 (GND), U8.3 (REF2); also elsewhere on the board
unnamed: C12.1, R25.2, RV7.1, U9.1 (ADJ)
unnamed: D13.1 (K), R33.1
unnamed: D14.1 (K), R34.1
unnamed: D15.2 (A), Q4.3 (C), RY1.16
unnamed: D16.1 (K), R41.1
unnamed: D17.2 (A), Q5.3 (C), RY2.16
unnamed: D18.2 (A), Q6.3 (C), RY4.16
unnamed: D19.1 (K), R43.1
unnamed: JP1.2 (C), R35.2
unnamed: Q2.1 (B), R35.1
unnamed: Q2.2 (E), Q3.1 (B)
unnamed: Q3.3 (E), R37.2
unnamed: Q4.1 (B), R38.2
unnamed: Q5.1 (B), R42.2
unnamed: Q6.1 (B), R26.2
Rly1: D13.2 (A), R38.1; also elsewhere on the board
Rly2: D14.2 (A), R42.1; also elsewhere on the board
Rly4: D19.2 (A), R26.1; also elsewhere on the board
Rs+: R36.2, U8.8 (+)
Rs-: R36.4, U8.1 (-)
base: JP1.1 (A); also elsewhere on the board
bat+: B1.1 (+), B1.3 (+), J5.1, J5.2, RY1.4; also elsewhere on the board
bat-: B1.2 (-), B1.4 (-), E1.3 (S-), E1.7 (F-), J6.1, J6.2, P4.1, R41.2, RY4.13; also elsewhere on the board
bat-2: Q2.3 (C), Q3.2 (C), RY4.11
disChar: D16.2 (A), P3.1, RY2.6
mid: R36.3, RY1.6

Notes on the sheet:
Gain=50 V/V
Max=5V
Vout=1.25V(1+R2/R1)+Iadj*R2=4.2V
4.2V/1.5A

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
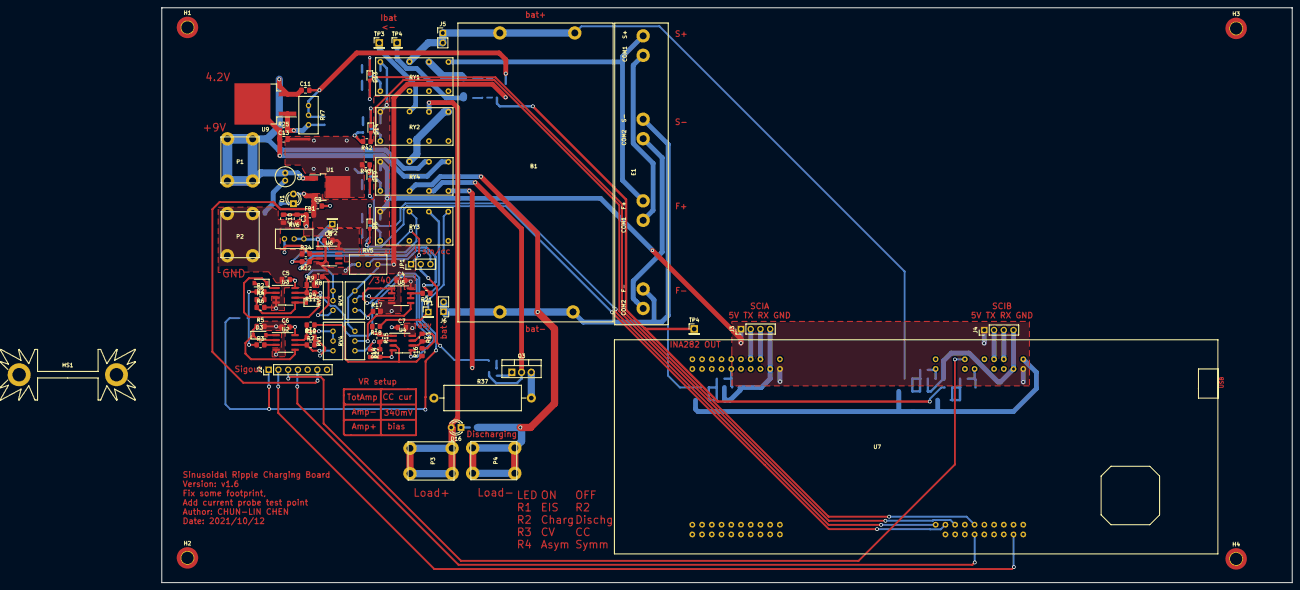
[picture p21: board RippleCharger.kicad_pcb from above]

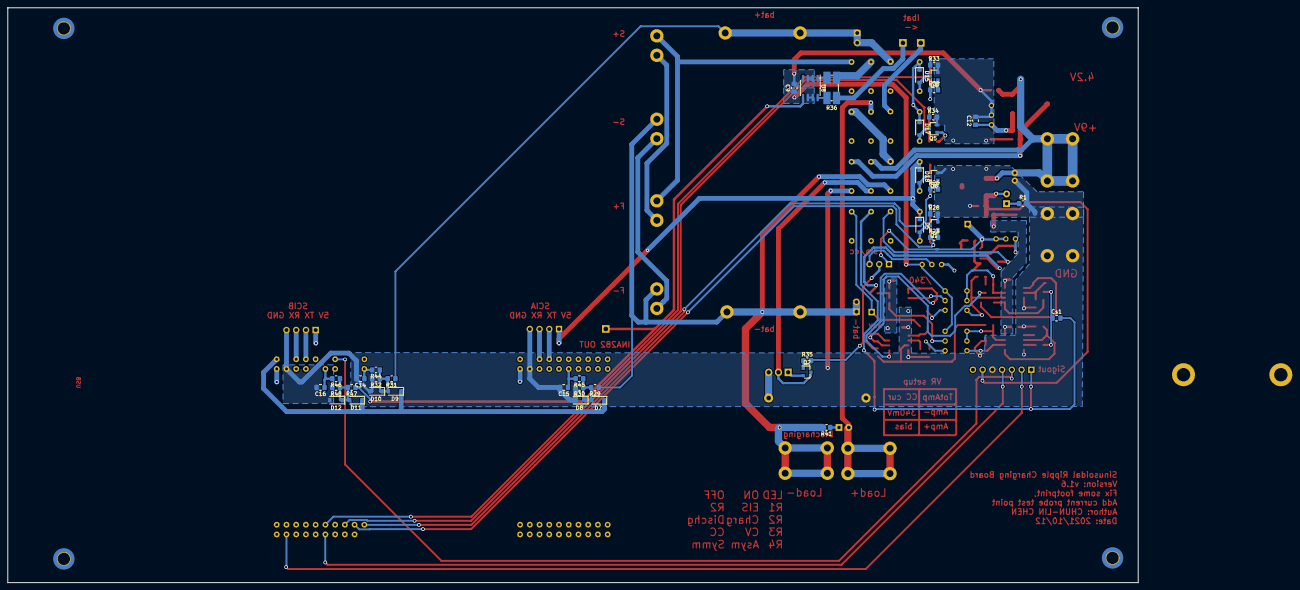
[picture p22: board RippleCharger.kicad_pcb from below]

Board: 2 copper layers, 295.0 x 150.0 mm, 129 parts (41 on the bottom side), 82 nets.

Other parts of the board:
TP4#2: Iprob-; PinHeader_1x01_P2.54mm_Vertical

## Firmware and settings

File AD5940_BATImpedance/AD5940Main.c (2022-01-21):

/*!
 *****************************************************************************
 @file:    AD5940Main.c
 @author:  Neo Xu
 @brief:   Used to control specific application and process data.
 -----------------------------------------------------------------------------
Copyright (c) 2017-2019 Analog Devices, Inc. All Rights Reserved.
This software is proprietary to Analog Devices, Inc. and its licensors.
By using this software you agree to the terms of the associated
Analog Devices Software License Agreement.
 
*****************************************************************************/
/** 
 * @addtogroup AD5940_System_Examples
 * @{
 *  @defgroup Battery_Example
 *  @{
  */
#include "ad5940.h"
#include <stdio.h>
#include "string.h"
#include "math.h"
#include "BATImpedance.h"
#include <stdbool.h>

#define APPBUFF_SIZE 512
uint32_t AppBuff[APPBUFF_SIZE];

char recvData[32];     // Data from SCIA RX
char recvBuff[32];
bool frecvFreq, NL, freqUpdate;
float recvFloat = 0.0;

extern AppBATCfg_Type AppBATCfg;
const char *TI_ACK = "A5A5\n";     						// receive TI_ACK from 0049
const char *ADI_ACK = "5A5A\n";     					// send ADI_ACK to 0049
const char *AD5940_Init_Done = "ID\n";     		// send initial done to 0049
const char *AD5940_Measure = "MS\n";           	// receive start measure signal from 0049
const char *AD5940_Measure_Done = "MD\n";			// send measure done to 0049

/* It's your choice here how to do with the data. Here is just an example to print them to UART */
int32_t BATShowResult(uint32_t *pData, uint32_t DataCount)
{
  fImpCar_Type *pImp = (fImpCar_Type*)pData;
	float freq;
	float Ztot = 0;
	AppBATCtrl(BATCTRL_GETFREQ, &freq);
  /*Process data*/
  for(int i=0;i<DataCount;i++)
  {
		Ztot = sqrt(pow(pImp[i].Real,2) + pow(pImp[i].Image,2));
		printf("F\n");
		printf("%4.2f\n",freq);
		printf("Z\n");
		printf("%3.4f\n",Ztot);
//		printf("%4.2f %3.4f \r\n",freq, Ztot);
  }
  return 0;
}

/* Initialize AD5940 basic blocks like clock */
static int32_t AD5940PlatformCfg(void)
{
  CLKCfg_Type clk_cfg;
  FIFOCfg_Type fifo_cfg;
  AGPIOCfg_Type gpio_cfg;
  /* Use hardware reset */
  AD5940_HWReset();
  /* Platform configuration */
  AD5940_Initialize();
  /* Step1. Configure clock */
  clk_cfg.ADCClkDiv = ADCCLKDIV_1;
  clk_cfg.ADCCLkSrc = ADCCLKSRC_HFOSC;
  clk_cfg.SysClkDiv = SYSCLKDIV_1;
  clk_cfg.SysClkSrc = SYSCLKSRC_HFOSC; //on battery board, there is a 32MHz crystal.
  clk_cfg.HfOSC32MHzMode = bFALSE;
  clk_cfg.HFOSCEn = bTRUE;
  clk_cfg.HFXTALEn = bFALSE;
  clk_cfg.LFOSCEn = bTRUE;
  AD5940_CLKCfg(&clk_cfg);
  /* Step2. Configure FIFO and Sequencer*/
  fifo_cfg.FIFOEn = bFALSE;
  fifo_cfg.FIFOMode = FIFOMODE_FIFO;
  fifo_cfg.FIFOSize = FIFOSIZE_4KB;                       /* 4kB for FIFO, The reset 2kB for sequencer */
  fifo_cfg.FIFOSrc = FIFOSRC_DFT;
  fifo_cfg.FIFOThresh = 4;//AppBATCfg.FifoThresh;        /* DFT result. One pair for RCAL, another for Rz. One DFT result have real part and imaginary part */
  AD5940_FIFOCfg(&fifo_cfg);                             /* Disable to reset FIFO. */
  fifo_cfg.FIFOEn = bTRUE;  
  AD5940_FIFOCfg(&fifo_cfg);                             /* Enable FIFO here */
  
  /* Step3. Interrupt controller */
  AD5940_INTCCfg(AFEINTC_1, AFEINTSRC_ALLINT, bTRUE);           /* Enable all interrupt in Interrupt Controller 1, so we can check INTC flags */
  AD5940_INTCCfg(AFEINTC_0, AFEINTSRC_DATAFIFOTHRESH, bTRUE);   /* Interrupt Controller 0 will control GP0 to generate interrupt to MCU */
  AD5940_INTCClrFlag(AFEINTSRC_ALLINT);
  /* Step4: Reconfigure GPIO */
  gpio_cfg.FuncSet = GP0_INT|GP2_SYNC;
  gpio_cfg.InputEnSet = AGPIO_Pin2;
  gpio_cfg.OutputEnSet = AGPIO_Pin0|AGPIO_Pin2;
  gpio_cfg.OutVal = 0;
  gpio_cfg.PullEnSet = 0;
  AD5940_AGPIOCfg(&gpio_cfg);
  AD5940_SleepKeyCtrlS(SLPKEY_UNLOCK);  /* Allow AFE to enter sleep mode. */
  return 0;
}

void AD5940BATStructInit(void)
{
  AppBATCfg_Type *pBATCfg;
  AppBATGetCfg(&pBATCfg);
  pBATCfg->SeqStartAddr = 0;
  pBATCfg->MaxSeqLen = 512;
  pBATCfg->RcalVal = 50.0;  							/* Value of RCAL on EVAL-AD5941BATZ board is 50mOhm */
  pBATCfg->ACVoltPP = 300.0f;							/* Pk-pk amplitude is 300mV */
  pBATCfg->DCVolt = 1200.0f;							/* Offset voltage of 1.2V*/
  pBATCfg->DftNum = DFTNUM_8192;
  
  pBATCfg->FifoThresh = 2;      					/* 2 results in FIFO, real and imaginary part. */
	if(recvFloat == 0)
		pBATCfg->SinFreq = 500.0;									/* Sin wave frequency. This value has no effect if sweep is enabled */
	pBATCfg->SweepCfg.SweepEn = bFALSE;			/* Set to bTRUE to enable sweep function */
	pBATCfg->SweepCfg.SweepStart = 500.0f;		/* Start sweep at 1Hz  */
	pBATCfg->SweepCfg.SweepStop = 20000.0f;	/* Finish sweep at 1000Hz */
	pBATCfg->SweepCfg.SweepPoints = 30;			/* 100 frequencies in the sweep */
	pBATCfg->SweepCfg.SweepLog = bTRUE;			/* Set to bTRUE to use LOG scale. Set bFALSE to use linear scale */
	
}

void AD5940_ChgSinFreq(float freq){
	AppBATCfg_Type *pBATCfg;
  AppBATGetCfg(&pBATCfg);
	if(freq <= 10.0)												/* Not using the data smaller then 10*/
		return;
	pBATCfg->SinFreq = freq;
}

void AD5940_Main(void)
{
  uint32_t temp;
  AD5940PlatformCfg();
	AD5940_Delay10us(100000);
	printf(AD5940_Init_Done);								/* Inform TI 0049 initial done */
	freqUpdate = true;
  while(1){
		AD5940BATStructInit(); 								/* Configure your parameters in this function */
		AppBATInit(AppBuff, APPBUFF_SIZE);    /* Initialize BAT application. Provide a buffer, which is used to store sequencer commands */
		AppBATCtrl(BATCTRL_MRCAL, 0);     		/* Measur RCAL of specific point*/
		AppBATCtrl(BATCTRL_START, 0);					/* Measure BAT impedance */
		while(1)
		{
			if((AD5940_GetMCUIntFlag() && freqUpdate && !AppBATCfg.SweepCfg.SweepEn))			    /* Check if interrupt flag which will be set when interrupt occurred, and frequency been updated by UART interrupt */
			{	
				freqUpdate = false;							/* Clear freqUpdate flag */
				temp = APPBUFF_SIZE;
				AppBATISR(AppBuff, &temp); 			/* Deal with it and provide a buffer to store data we got */
				BATShowResult(AppBuff, temp);		/* Print measurement results over UART */		
				AD5940_ChgSinFreq(recvFloat);		/* Change AppBATCfg.SinFreq to new frequency */
				AD5940_SEQMmrTrig(SEQID_0);  		/* Trigger next measurement ussing MMR write*/
				AD5940_ClrMCUIntFlag(); 				/* Clear this flag */	
				AppBATCfg.bParaChanged = bTRUE;	/* inform AppBATInit parameter had bene changed */
				break;													/* Break the second while loop to reset parameters of AppBATCfg */
			}
			else if (AD5940_GetMCUIntFlag() && AppBATCfg.SweepCfg.SweepEn){
				temp = APPBUFF_SIZE;
				AppBATISR(AppBuff, &temp); 			/* Deal with it and provide a buffer to store data we got */
				BATShowResult(AppBuff, temp);		/* Print measurement results over UART */		
				AD5940_ChgSinFreq(recvFloat);		/* Change AppBATCfg.SinFreq to new frequency */
				AD5940_SEQMmrTrig(SEQID_0);  		/* Trigger next measurement ussing MMR write*/
				AD5940_ClrMCUIntFlag(); 				/* Clear this flag */	
			}
			AD5940_Delay10us(100);
		}
  }
}

/**
 * @}
 * @}
 * */

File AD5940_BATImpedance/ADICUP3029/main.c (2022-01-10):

/*
Copyright (c) 2017-2019 Analog Devices, Inc. All Rights Reserved.

This software is proprietary to Analog Devices, Inc. and its licensors.
By using this software you agree to the terms of the associated
Analog Devices Software License Agreement.
*/ 

#include "stdio.h"
#include "ADuCM3029.h"
#include "AD5940.h"

/* Functions that used to initialize MCU platform */
uint32_t MCUPlatformInit(void *pCfg);

int main(void)
{
  void AD5940_Main(void);
  MCUPlatformInit(0);
  AD5940_MCUResourceInit(0);
  //printf("Hello AD5940-Build Time:%s\n\r",__TIME__);
  AD5940_Main();
}

/* Below functions are used to initialize MCU Platform */
uint32_t MCUPlatformInit(void *pCfg)
{
  int UrtCfg(int iBaud);

  /*Stop watch dog timer(ADuCM3029)*/
  pADI_WDT0->CTL = 0xC9;
  /* Clock Configure */
  pADI_CLKG0_OSC->KEY = 0xCB14;               // Select HFOSC as system clock.
  pADI_CLKG0_OSC->CTL =                       // Int 32khz LFOSC selected in LFMUX
    BITM_CLKG_OSC_CTL_HFOSCEN|BITM_CLKG_OSC_CTL_HFXTALEN;

  while((pADI_CLKG0_OSC->CTL&BITM_CLKG_OSC_CTL_HFXTALOK) == 0);

  pADI_CLKG0_OSC->KEY = 0xCB14; 
  pADI_CLKG0_CLK->CTL0 = 0x201;                   /* Select XTAL as system clock */
  pADI_CLKG0_CLK->CTL1 = 0;                   // ACLK,PCLK,HCLK divided by 1
  pADI_CLKG0_CLK->CTL5 = 0x00;                 // Enable clock to all peripherals - no clock gating

  UrtCfg(115200);/*Baud rate: 230400*/
  return 1;
}

/**
	@brief int UrtCfg(int iBaud, int iBits, int iFormat)
			==========Configure the UART.
	@param iBaud :{B1200,B2200,B2400,B4800,B9600,B19200,B38400,B57600,B115200,B230400,B430800}	\n
		Set iBaud to the baudrate required:
		Values usually: 1200, 2200 (for HART), 2400, 4800, 9600,
		        19200, 38400, 57600, 115200, 230400, 430800, or type in baud-rate directly
	@note
		- Powers up UART if not powered up.
		- Standard baudrates are accurate to better than 0.1% plus clock error.\n
		- Non standard baudrates are accurate to better than 1% plus clock error.
   @warning - If an external clock is used for the system the ullRtClk must be modified with \n
         the speed of the clock used.
**/

int UrtCfg(int iBaud)
{
  int iBits = 3;//8bits, 
  int iFormat = 0;//, int iBits, int iFormat
  int i1;
  int iDiv;
  int iRtC;
  int iOSR;
  int iPllMulValue;
  unsigned long long ullRtClk = 16000000;                // The root clock speed


  /*Setup P0[11:10] as UART pins*/
  pADI_GPIO0->CFG = (1<<22)|(1<<20)|(pADI_GPIO0->CFG&(~((3<<22)|(3<<20))));

  iDiv = (pADI_CLKG0_CLK->CTL1& BITM_CLKG_CLK_CTL1_PCLKDIVCNT);                 // Read UART clock as set by CLKCON1[10:8]
  iDiv = iDiv>>8;
  if (iDiv == 0)
    iDiv = 1;
  iRtC = (pADI_CLKG0_CLK->CTL0& BITM_CLKG_CLK_CTL0_CLKMUX); // Check what is the root clock

  switch (iRtC)
  {
  case 0:                                               // HFOSC selected
    ullRtClk = 26000000;
    break;

  case 1:                                               // HFXTAL selected
    if ((pADI_CLKG0_CLK->CTL0 & 0x200)==0x200)           // 26Mhz XTAL used
        ullRtClk = 26000000;
    else
        ullRtClk = 16000000;                              // Assume 16MHz XTAL
    break;

  case 2:                                               // SPLL output
    iPllMulValue = (pADI_CLKG0_CLK->CTL3 &             // Check muliplication factor in PLL settings
                    BITM_CLKG_CLK_CTL3_SPLLNSEL);      // bits[4:0]. Assume div value of 0xD in bits [14:11]
    ullRtClk = (iPllMulValue *1000000);                // Assume straight multiplication by pADI_CLKG0_CLK->CTL3[4:0]
    break;

  case 3:
    ullRtClk = 26000000;                                //External clock is assumed to be 26MhZ, if different
    break;                                             //clock speed is used, this should be changed

  default:
    break;
  }
  //   iOSR = (pADI_UART0->COMLCR2 & 0x3);
  //   iOSR = 2^(2+iOSR);
  pADI_UART0->COMLCR2 = 0x3;
  iOSR = 32;
  //i1 = (ullRtClk/(iOSR*iDiv))/iBaud;	              // UART baud rate clock source is PCLK divided by OSR
  i1 = (ullRtClk/(iOSR*iDiv))/iBaud-1;   //for bigger M and N value
  pADI_UART0->COMDIV = i1;

  pADI_UART0->COMFBR = 0x8800|(((((2048/(iOSR*iDiv))*ullRtClk)/i1)/iBaud)-2048);
  pADI_UART0->COMLCR = (iFormat&0x3c)|(iBits&3);


  pADI_UART0->COMFCR = (BITM_UART_COMFCR_RFTRIG & 0/*RX_FIFO_1BYTE*/ ) |BITM_UART_COMFCR_FIFOEN;
  pADI_UART0->COMFCR |= BITM_UART_COMFCR_RFCLR|BITM_UART_COMFCR_TFCLR;                                   // Clear the UART FIFOs
  pADI_UART0->COMFCR &= ~(BITM_UART_COMFCR_RFCLR|BITM_UART_COMFCR_TFCLR);                                // Disable clearing mechanism

  NVIC_EnableIRQ(UART_EVT_IRQn);              // Enable UART interrupt source in NVIC
  pADI_UART0->COMIEN = BITM_UART_COMIEN_ERBFI|BITM_UART_COMIEN_ELSI; /* Rx Interrupt */
  return pADI_UART0->COMLSR;
}
#include "stdio.h"
#ifdef __ICCARM__
int putchar(int c)
#else
int fputc(int c, FILE *f)
#endif
{
  pADI_UART0->COMTX = c;
  while((pADI_UART0->COMLSR&0x20) == 0);// tx fifo empty
  return c;
}

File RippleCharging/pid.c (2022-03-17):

/*
 * pid.c
 *
 */

#include    "pid.h"

static PID_STRUCT sPID;

PID_STRUCT* Init_pid(void)
{
    // Set PID Coefficients
    sPID.Kp = 0.1;

    sPID.Ki = 0.0005;

    sPID.Kd = 0;

    // Set PID Setpoint
    sPID.RefSetPoint = 1871.5;            // Default output current average 2.6A

    sPID.OutputMax = 1750;
    sPID.OutputMin = 1650;
    sPID.Error_2 = 0;
    sPID.Error_1 = 0;
    sPID.LastOutput = 0.0;
    return &sPID;
}

void pid_process(PID_STRUCT *psPID)
{
    // Compute the error
    psPID->Error = -(psPID->RefSetPoint - psPID->Feedback_AdcPoint);

    // Compute the proportional output
    //psPID->Up = psPID->Kp * psPID->Error;
    psPID->incOutput = psPID->Kp * (psPID->Error - psPID->Error_1);

    // Compute the integral output
    //psPID->Ui = psPID->Ui + (psPID->Ki * psPID->Up) + (psPID->Kc * psPID->SatErr);
    psPID->incOutput += psPID->Ki * (psPID->Error + psPID->Error_1);

    // Compute the derivative output
    //psPID->Ud = psPID->Kd * (psPID->Up - psPID->Up1);
    psPID->incOutput += psPID->Kd * (psPID->Error - 2 * psPID->Error_1 + psPID->Error_2);

    psPID->Output = psPID->LastOutput + psPID->incOutput;

    // Saturate the output
    if (psPID->Output > psPID->OutputMax)
        psPID->Output = psPID->OutputMax;

    else if (psPID->Output < psPID->OutputMin)
        psPID->Output = psPID->OutputMin;

    // Update the previous output
    psPID->LastOutput = psPID->Output;

    // Update last error
    psPID->Error_2 = psPID->Error_1;
    psPID->Error_1 = psPID->Error;

}

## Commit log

2021-09-23 Add ADICUP3029 EIS base board firmware
2021-10-15 Update PCB layout m include relay footprint, board outlook.Modify Main 0049 code and add CV function
    [Battery.sch, Control.sch, Power.sch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]
2021-10-15 Fix CV charging route
    [Battery.sch, Control.sch, RippleCharger.kicad_pcb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]
2021-10-25 Fix Layout error and adjust firmware ADC tradshold
    [Battery.sch]
2021-10-26 Add UART function into F280049, and fix the CV status ADC value. Change ADICUP3029 baudrate, modify UART return character into \r\n
    [AD5940Main.c, BATImpedance.c, Init.c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]
2021-11-22 Modify SRC charging code, Modify CN0510 code add CLI driver from original source
2021-11-22 Add new SRC CCCV board, add battery holder footpront into library
    [CVModule-B_Cu.gbr, CVModule-B_Mask.gbr, CVModule-B_Paste.gbr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]
2021-12-27 Fix single frequency test accuricy and add uart driver into ADICUP3029 code
    [AD5940Main.c, BATImpedance.c, ad5940.c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]
2022-01-10 Add UART communication in 3029, transmit and receive command successfully but not implement impedance request yet
2022-01-11 Fix uart FIFO issue, optimize 3029 uart RXIST size,implement AppBATCfg modifier, move IDE project location into git directory, remove none used file
    [AD5940Main.c, ADICUP3029Port.c, main.c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]
2022-01-18 Add single frequency test function, re-measure AppBATCfg.RcalVolt every time when frequency updated by UART from TI MCU. Reduce PreCharge function delay time to speedup measurement performence. ISSUE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
    [AD5940Main.c, BATImpedance.c]
2022-01-20 Add dual slope search method, fix bug of transmit float to 3029
    [AD5940Main.c, Init.c]
2022-01-21 Add P&O method in the end of dual slope search, fix impIdx duplicate issue
    [AD5940Main.c]
2022-03-17 Change FIR cutoff frequency, add pid controller to stablize current at 2.6A
